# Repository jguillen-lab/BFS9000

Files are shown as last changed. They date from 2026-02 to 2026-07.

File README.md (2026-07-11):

# BFS9000 — Umbrella repository (hardware + firmware + software)

> 🇪🇸 **¿Prefieres leer esto en español?** → [README.es.md](README.es.md)

Main repository that groups several subprojects around the **BFS9000** keyboard (hardware) and its ecosystem of **QMK/Vial firmware** and **PC software** to control lighting over the network (Home Assistant via MQTT, with a local agent that talks to the keyboard over USB).

<p align="center">
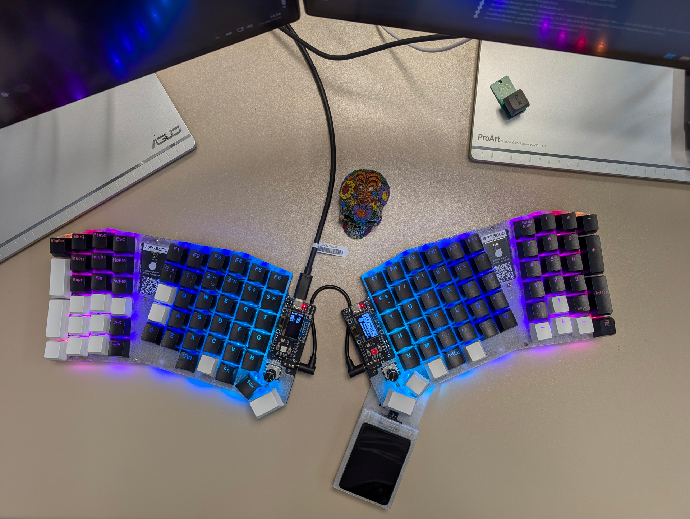
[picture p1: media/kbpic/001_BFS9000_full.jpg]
BFS9000 full keyboard
  
</p>

<p align="center">
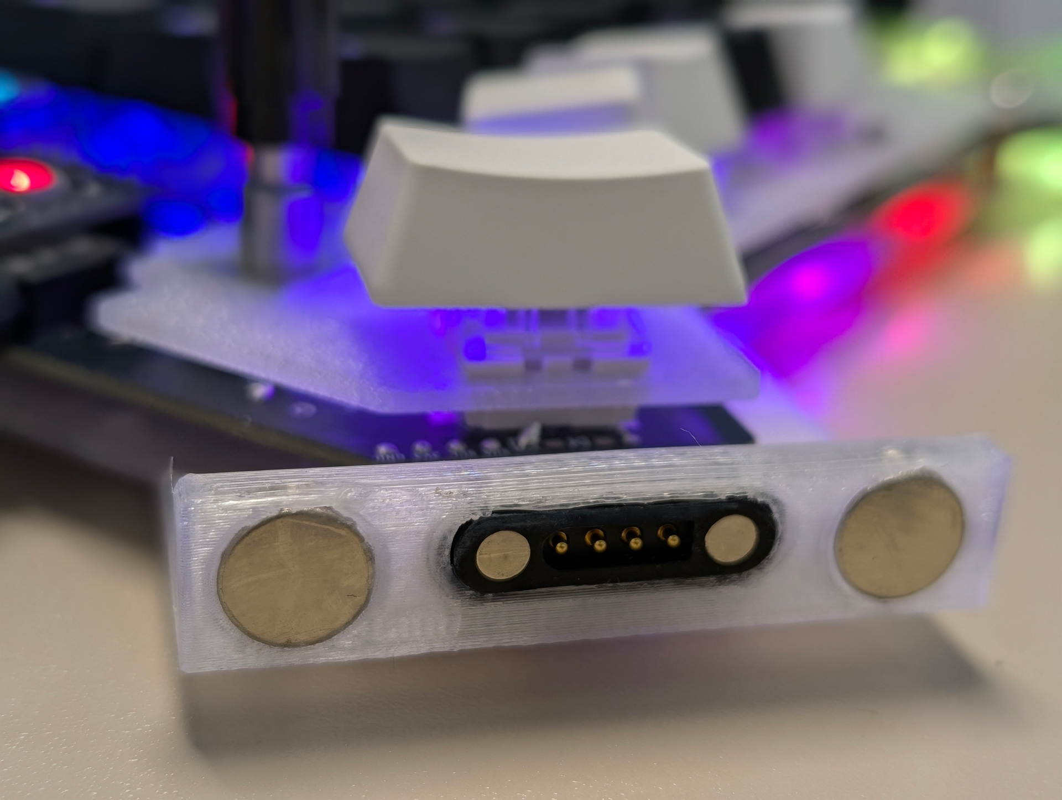
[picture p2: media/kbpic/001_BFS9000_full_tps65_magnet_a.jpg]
BFS9000 TPS65 magnet view A
  
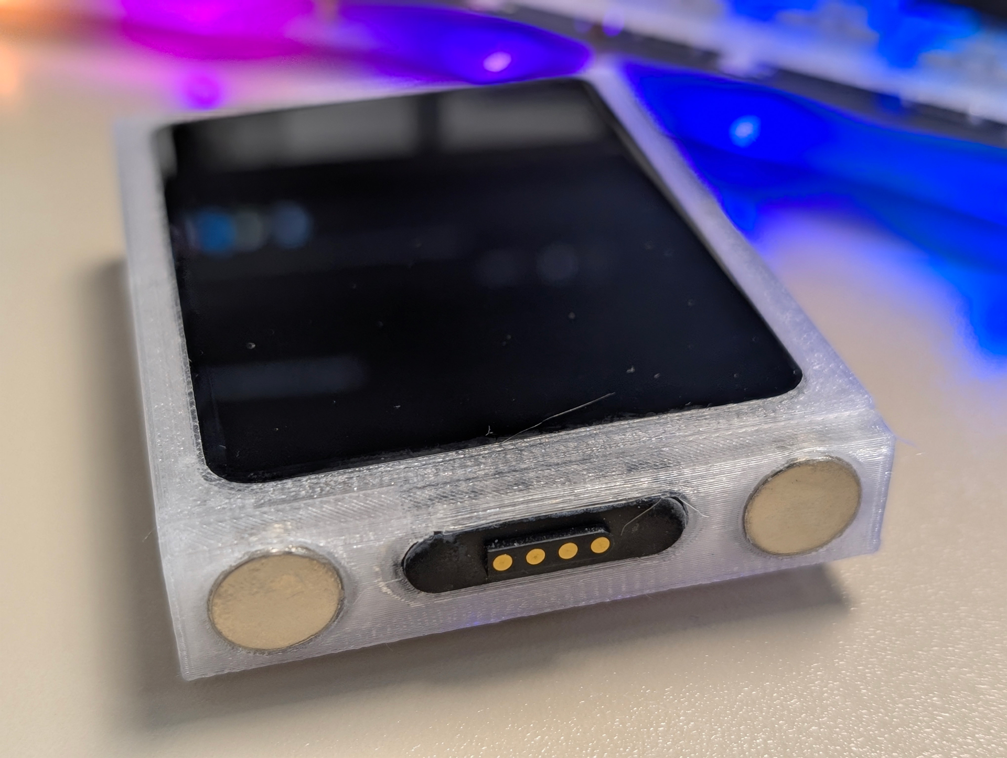
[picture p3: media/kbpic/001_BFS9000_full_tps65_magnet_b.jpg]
BFS9000 TPS65 magnet view B
  
</p>

## Repository structure

- [`hardware/`](./hardware/) — keyboard/PCB design (BFS9000) and related documentation.
- [`firmware/`](./firmware/) — firmware based on QMK/Vial, including configuration, keymaps, and related files.
- [`software/`](./software/) — PC agent/CLI for USB, MQTT, and Home Assistant integration.
- [`media/`](./media/) — general multimedia assets used throughout the project, such as images, videos, and other shared resources.
- [`hodgepodge/`](./hodgepodge/) — tests, experiments, and auxiliary material.
- [Wiki](https://github.com/jguillen-lab/BFS9000/wiki) — extended project documentation, guides, and additional reference material.

> Each folder should (or will eventually) have its own README with specific instructions.

## Community builds

Built your own BFS9000? Show it off here! Instructions and a ready-to-use template: [`media/kbpic/README.md`](media/kbpic/README.md). See the full gallery: [`media/GALLERY.md`](media/GALLERY.md).

<p align="center">
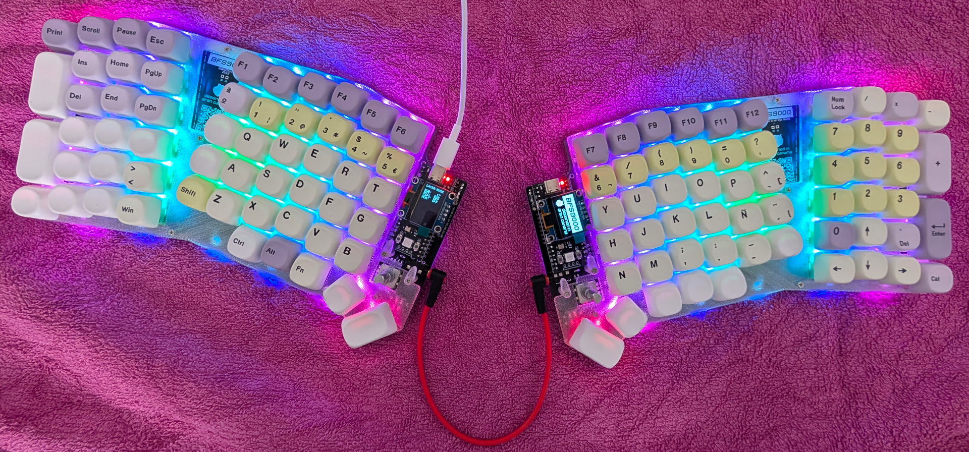
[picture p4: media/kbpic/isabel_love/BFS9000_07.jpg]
  
</p>

<p align="center"><i>Isabel Love — <a href="media/kbpic/isabel_love/README.md">more photos</a></i></p>

## Motivation

Standard keyboards never worked for me: I’d always end up placing them diagonally, and the classic staggered layout eventually took its toll (discomfort and some finger deformation). About ~10 years ago I got into the custom keyboard world and started looking for split, more ergonomic options: first I looked at commercial designs like the ErgoDox, then I tried the Corne, until I finally found the **[Sofle](https://github.com/josefadamcik/SofleKeyboard)**, originally designed and maintained by **Josef Adamčík**.

My first keyboard purchase was from **[Mechboards (UK)](https://mechboards.co.uk/)**. My first build attempt was a disaster, but in my case they were really helpful with support. (Note: their returns/warranty policy may differ today and, as they indicate, it usually doesn’t cover modified/soldered products; check it before buying.)
- Current policy (reference): https://mechboardsuk.reamaze.com/kb/shipping-and-returns/returns-policy

My second Sofle was a **Sofle RGB** from **[KeyHive](https://keyhive.xyz/shop/sofle)**. Within the Sofle ecosystem, the **Sofle RGB** variant (per-key RGB + underglow) is commonly attributed as a contribution by **Dane Evans** to the Sofle project.

Over time I’ve had other keyboards based on Sofle with small modifications and even had custom PCBs manufactured. The change was real: my fingers improved and my speed went up; in fact, when I go back to a staggered keyboard now I feel incredibly clumsy.

Even so, although I set up layers and learned to use them comfortably, I’m not the kind of person who “lives” in layers. After ~8 years using the Sofle I decided to try a **[BFO9000](https://docs.keeb.io/bfo-9000-build-guide)** (de **Keebio**) in its full configuration. Ergonomically I like it much less, but it solved my day-to-day better.

I thought that missing the Sofle would fade with time… but it didn’t. That’s why I’m in the process of creating a **BFS9000**, based on JellyTitan’s latest iteration called **[Sofle-Pico](https://github.com/JellyTitan/Sofle-Pico)**:

## Variants and combinations

One of the main goals of BFS9000 is flexibility.

The same PCB can be used to build multiple physical configurations, allowing different combinations of enclosures, plates and trackpad-related parts.

In total, the current design supports **16 different combinations** from the same PCB base.

<p align="center">
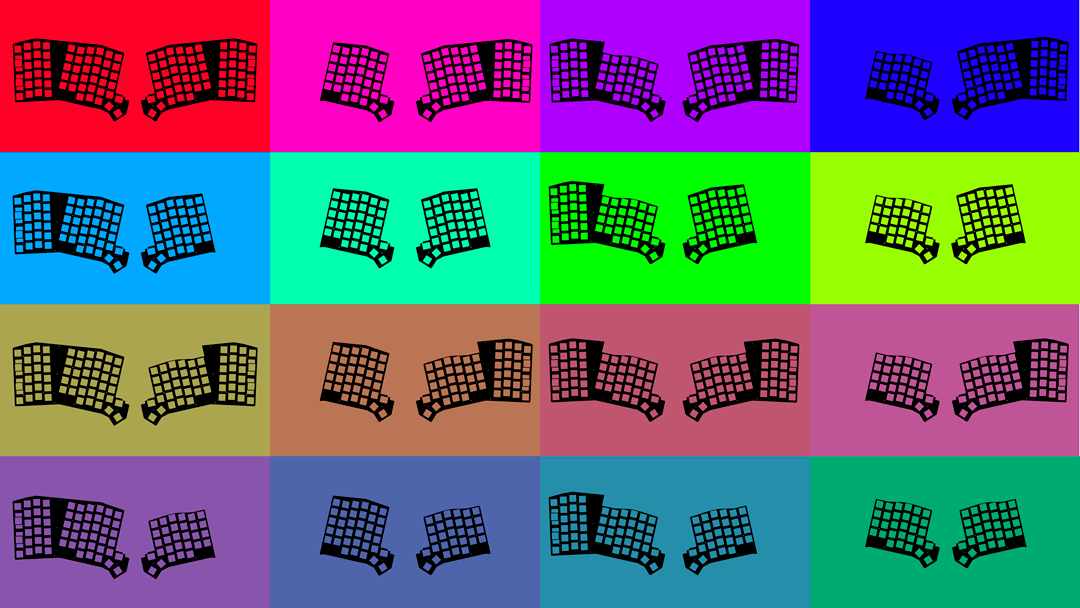
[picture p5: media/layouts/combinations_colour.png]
BFS9000 combinations overview
  
</p>

## Subprojects (quick links)

- BFS9000 hardware: [`hardware/`](./hardware/)
- Firmware (QMK/Vial): [`firmware/`](./firmware/)
- Software (PC agent / MQTT / HA): [`software/`](./software/)
- Auxiliary material: [`hodgepodge/`](./hodgepodge/)

## References

### Designs
- Sofle (Josef Adamčík): https://github.com/josefadamcik/SofleKeyboard
- Sofle-Pico (JellyTitan): https://github.com/JellyTitan/Sofle-Pico
- Sofle-Pico docs/site: https://www.soflepico.com/
- BFO-9000 (Keebio): https://docs.keeb.io/bfo-9000-build-guide

### Stores
- Mechboards: https://mechboards.co.uk/
- KeyHive (Sofle RGB): https://keyhive.xyz/shop/sofle

### Firmware / HA
- Vial (manual): https://get.vial.today/manual/
- Home Assistant MQTT: https://www.home-assistant.io/integrations/mqtt/
- Home Assistant MQTT Light: https://www.home-assistant.io/integrations/light.mqtt/

## License

**EN:** This repository uses **multiple licenses**. The applicable license(s) for each component are included in a `LICENSE` file within the **relevant directory**.

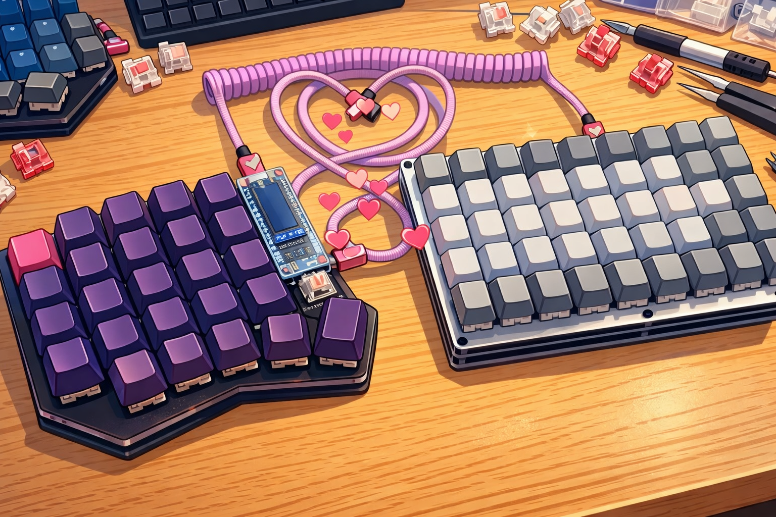
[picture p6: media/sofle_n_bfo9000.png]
Sofle y BFO9000


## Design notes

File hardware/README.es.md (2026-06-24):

# Hardware BFS9000

> 🇬🇧 **Prefer to read this in English?** → [README.md](README.md)

Esta carpeta contiene los ficheros de hardware de **BFS9000**, un teclado split diseñado por Jesús Guillén.

La revisión estable actual de hardware es la **0.4**.

---

## 1) Estructura de carpetas

```text
hardware/
├── BFS9000/              Ficheros fuente KiCad de la PCB principal
├── production/           Ficheros listos para fabricación
│   └── rev0.4/
│       ├── pcb/          Gerbers y taladros de la PCB principal
│       └── plates/       Ficheros de switch plate y bottom plate opcionales
└── enclosures/           Ficheros de carcasa y corte láser/CNC
    └── rev0.4/
```

La carpeta `BFS9000/` contiene el proyecto KiCad editable.

La carpeta `production/` contiene ficheros pensados para enviarse directamente a fabricar.

La carpeta `enclosures/` contiene ficheros opcionales de carcasa y ficheros para corte CNC/láser.

---

## 2) Revisiones de hardware

### Revisión 0.2

La revisión **0.2** usaba una **PCB de cuatro capas**.

Esta revisión tenía un fallo fatal de hardware causado por una huella incorrecta en los LEDs. Se conserva únicamente como referencia histórica y no debería usarse para fabricar nuevas placas.

### Revisión 0.3

La revisión **0.3** corrigió los fallos críticos encontrados en la revisión 0.2.

Además, cambió la PCB de **cuatro capas a dos capas**, simplificando el diseño y facilitando su fabricación.

### Revisión 0.4

La revisión **0.4** es la revisión estable actual de hardware.

Mantiene las correcciones de la revisión 0.3 y optimiza la PCB de forma general.

---

## 3) Ficheros de producción

Los ficheros listos para fabricar de la revisión 0.4 están en:

```text
hardware/production/rev0.4/
```

### PCB principal

```text
hardware/production/rev0.4/pcb/
└── BFS9000-rev0.4-pcb-gerbers-drill.zip
```

Este archivo contiene los Gerbers y taladros de la PCB principal de BFS9000.

También se incluyen estas imágenes de previsualización:

```text
BFS9000-rev0.4-gerber-preview.png
BFS9000-rev0.4-drill-preview.png
```

### Placas opcionales

```text
hardware/production/rev0.4/plates/
├── BFS9000-rev0.4-switch-plate.zip
└── BFS9000-rev0.4-bottom-plate.zip
```

La **BFS9000 switch plate** y la **BFS9000 bottom plate** son opcionales.

Normalmente se fabrican en **PMMA**.

---

## 4) Carcasas y ficheros CNC

Los ficheros de carcasa de la revisión 0.4 están en:

```text
hardware/enclosures/rev0.4/
```

### Serie A — carcasa seccionable

Los ficheros que empiezan por `A_` pertenecen a la versión de carcasa **seccionable**.

Se usa:

```text
A_BFS9000_sectionable_switch.3mf
```

Y después se elige solo una pieza inferior:

```text
A_BFS9000_sectionable_bottom.3mf
A_BFS9000_sectionable_bottom_tps65.3mf
```

Usa la versión `*_tps65` si el montaje del teclado incluye el **trackpad TPS65**.

### Serie B — carcasa completa

Los ficheros que empiezan por `B_` pertenecen a la versión de carcasa **completa**, no seccionable.

Esta versión solo sirve para la versión completa del teclado:

```text
B_BFS9000_full_switch.3mf
B_BFS9000_full_bottom.3mf
B_BFS9000_full_bottom_tps65.3mf
```

Usa la pieza inferior `*_tps65` si el montaje del teclado incluye el **trackpad TPS65**.

### Serie C — carcasa completa con ventana

Los ficheros que empiezan por `C_` pertenecen a la versión de carcasa **completa**, no seccionable, con ventana.

La ventana permite ver la zona decorativa de la PCB, como el logo, el QR, la dedicatoria u otros detalles:

```text
C_BFS9000_full_with_window_switch.3mf
C_BFS9000_full_with_window_bottom.3mf
C_BFS9000_full_bottom_with_window_tps65.3mf
```

Usa la pieza inferior `*_tps65` si el montaje del teclado incluye el **trackpad TPS65**.

### Serie X — piezas para TPS65

Los ficheros que empiezan por `X_` son específicos de la carcasa del **trackpad TPS65**:

```text
X_tps65_bottom.3mf
X_tps65_frame.3mf
X_tps65_main_bottom_addon.3mf
```

### Ficheros CNC / corte láser

Los ficheros que empiezan por `CNC_` están pensados para corte CNC o corte láser, por ejemplo en **PMMA**:

```text
CNC_bottom.dxf
CNC_switch.dxf
CNC_screen.dxf
```

---

## 5) Tag estable de hardware

La revisión estable 0.4 del hardware se marcará con este tag de Git:

```text
hardware/bfs9000-rev0.4
```

Los tags de Git siempre apuntan a un commit completo del repositorio, no a una carpeta individual.
Aun así, se puede restaurar solo la parte de hardware desde ese tag.

Para restaurar únicamente la carpeta de hardware a la revisión 0.4:

```bash
git restore --source hardware/bfs9000-rev0.4 -- hardware
```

Para comparar los ficheros actuales de hardware contra la revisión 0.4:

```bash
git diff hardware/bfs9000-rev0.4 -- hardware
```

---

## 6) Flujo recomendado

Con el repositorio limpio:

```bash
git status --short
```

Crear un tag anotado:

```bash
git tag -a hardware/bfs9000-rev0.4 -m "BFS9000 hardware revision 0.4 stable"
```

Subir el tag a GitHub:

```bash
git push origin hardware/bfs9000-rev0.4
```

---

## 7) Licencia

Salvo que se indique lo contrario, los ficheros de esta carpeta se distribuyen bajo la licencia del repositorio.

Consulta el fichero [LICENSE](../LICENSE) en la raíz del repositorio para más detalles.

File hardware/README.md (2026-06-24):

# BFS9000 Hardware

> 🇪🇸 **¿Prefieres leer esto en español?** → [README.es.md](README.es.md)

This directory contains the hardware files for **BFS9000**, a custom split keyboard designed by Jesús Guillén.

The current stable hardware revision is **0.4**.

---

## 1) Directory structure

```text
hardware/
├── BFS9000/              KiCad source files for the main PCB
├── production/           Manufacturing-ready files
│   └── rev0.4/
│       ├── pcb/          Main PCB Gerbers and drill files
│       └── plates/       Optional switch and bottom plate files
└── enclosures/           Case, enclosure and laser-cutting files
    └── rev0.4/
```

The `BFS9000/` directory contains the editable KiCad project files.

The `production/` directory contains files intended to be sent directly to a PCB manufacturer.

The `enclosures/` directory contains optional case/enclosure files and CNC/laser-cutting files.

---

## 2) Hardware revisions

### Revision 0.2

Revision **0.2** used a **four-layer PCB**.

This revision had a fatal hardware issue caused by an incorrect LED footprint. It is kept only as historical reference and should not be used for new boards.

### Revision 0.3

Revision **0.3** corrected the critical issues found in revision 0.2.

It also changed the PCB from **four layers to two layers**, making the design simpler and easier to manufacture.

### Revision 0.4

Revision **0.4** is the current stable hardware revision.

It keeps the fixes from revision 0.3 and generally optimises the PCB layout.

---

## 3) Production files

Manufacturing-ready files for revision 0.4 are stored in:

```text
hardware/production/rev0.4/
```

### Main PCB

```text
hardware/production/rev0.4/pcb/
└── BFS9000-rev0.4-pcb-gerbers-drill.zip
```

This archive contains the Gerber and drill files for the main BFS9000 PCB.

The following preview images are also included:

```text
BFS9000-rev0.4-gerber-preview.png
BFS9000-rev0.4-drill-preview.png
```

### Optional plates

```text
hardware/production/rev0.4/plates/
├── BFS9000-rev0.4-switch-plate.zip
└── BFS9000-rev0.4-bottom-plate.zip
```

The **BFS9000 switch plate** and **BFS9000 bottom plate** are optional.

They are normally manufactured from **PMMA**.

---

## 4) Enclosures and CNC files

Case and enclosure files for revision 0.4 are stored in:

```text
hardware/enclosures/rev0.4/
```

### A series — sectionable enclosure

Files starting with `A_` belong to the **sectionable** enclosure version.

Use:

```text
A_BFS9000_sectionable_switch.3mf
```

Then choose only one bottom part:

```text
A_BFS9000_sectionable_bottom.3mf
A_BFS9000_sectionable_bottom_tps65.3mf
```

Use the `*_tps65` version if the keyboard build includes the **TPS65 trackpad**.

### B series — full enclosure

Files starting with `B_` belong to the **full**, non-sectionable enclosure version.

This version is intended for the complete keyboard:

```text
B_BFS9000_full_switch.3mf
B_BFS9000_full_bottom.3mf
B_BFS9000_full_bottom_tps65.3mf
```

Use the `*_tps65` bottom if the keyboard build includes the **TPS65 trackpad**.

### C series — full enclosure with window

Files starting with `C_` belong to the **full**, non-sectionable enclosure version with a window.

The window is intended to expose the PCB decoration area, such as the logo, QR code, dedication or other artwork:

```text
C_BFS9000_full_with_window_switch.3mf
C_BFS9000_full_with_window_bottom.3mf
C_BFS9000_full_bottom_with_window_tps65.3mf
```

Use the `*_tps65` bottom if the keyboard build includes the **TPS65 trackpad**.

### X series — TPS65 enclosure parts

Files starting with `X_` are specific to the **TPS65 trackpad** enclosure:

```text
X_tps65_bottom.3mf
X_tps65_frame.3mf
X_tps65_main_bottom_addon.3mf
```

### CNC / laser-cutting files

Files starting with `CNC_` are intended for CNC or laser cutting, for example in **PMMA**:

```text
CNC_bottom.dxf
CNC_switch.dxf
CNC_screen.dxf
```

---

## 5) Stable hardware tag

The stable hardware revision 0.4 is intended to be marked with this Git tag:

```text
hardware/bfs9000-rev0.4
```

Git tags always point to a full repository commit, not to an individual folder.
However, the hardware folder can be restored independently from that tag.

To restore only the hardware directory to revision 0.4:

```bash
git restore --source hardware/bfs9000-rev0.4 -- hardware
```

To compare the current hardware files against revision 0.4:

```bash
git diff hardware/bfs9000-rev0.4 -- hardware
```

---

## 6) Recommended workflow

With a clean repository:

```bash
git status --short
```

Create an annotated tag:

```bash
git tag -a hardware/bfs9000-rev0.4 -m "BFS9000 hardware revision 0.4 stable"
```

Push the tag to GitHub:

```bash
git push origin hardware/bfs9000-rev0.4
```

---

## 7) Licence

Unless stated otherwise, the files in this directory are distributed under the repository licence.

See the root [LICENSE](../LICENSE) file for details.

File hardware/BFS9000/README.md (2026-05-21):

# BFS9000 — Hardware

> 🇪🇸 **¿Prefieres leer esto en español?** ? [README.es.md](README.es.md)

Hardware directory for the **BFS9000** keyboard.

> **Work in progress**
>
> This hardware is currently under active development and is **not functional yet**.
> Version `0.4` should be considered an early prototype intended only for validation and iteration.
>
> Do **not** treat the current design, PCB, schematics, footprints, BOM, or documentation as final or production-ready.
> Expect breaking changes, missing features, design errors, and incomplete documentation.

## Status

- Current version: `0.4`
- Development stage: prototype / WIP
- Functional status: **not working yet**

## Notes

This directory is intended to track the ongoing hardware development of the BFS9000.
At this stage, the project is still evolving and substantial changes are expected before it becomes usable.

## License and attribution

This hardware directory is licensed under the MIT License unless otherwise stated.

BFS9000 contains original work as well as files, ideas, references, or derived work from other open-source keyboard projects and component libraries.

See:

- [LICENSE](LICENSE)
- [NOTICE.md](NOTICE.md)

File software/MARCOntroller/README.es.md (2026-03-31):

# MARCOntroller — Guía de uso

> 🇬🇧 **Prefer to read this in English?** → [README.md](README.md)

Control de LEDs **Marquichuelo** (QMK + Vial/VialRGB) por **USB HID** usando **VialRGB**.

MARCOntroller incluye actualmente varias capas:

- **CLI** para pruebas y control directo por USB HID.
- **UI de escritorio** para control local, configuración y gestión del servicio.
- **Agente MQTT** para integración con **Home Assistant**.
- **Servicio del sistema** para ejecución persistente en segundo plano.

La comunicación con el teclado usa el **interfaz RAW HID de VIA/Vial** (usagePage `0xFF60`, usage `0x0061`) y los comandos **VialRGB** ya presentes en el firmware, sin necesidad de añadir un `raw_hid_receive()` propio.

---

## 1) Requisitos

### Firmware

- Teclado con **Vial** y **VialRGB** habilitados (`VIALRGB_ENABLE = yes` + `RGB_MATRIX_ENABLE = yes`).
- Para control **LED a LED**: debe estar compilado el modo **VIALRGB_DIRECT** (si `get-led-count` funciona, lo tienes).

### PC

- Rust toolchain instalado (`rustc`, `cargo`).
- Drivers USB HID estándar.
- En **Windows**, si compilas con MSVC: Build Tools (C++ toolset + Windows SDK).
- En **Linux**, `hidapi` puede requerir dependencias del sistema como `libudev-dev` y `libhidapi-dev`.
- En **macOS**, el acceso HID usa las APIs del sistema.

---

## 2) Estructura del proyecto

~~~text
MARCOntroller/
├── Cargo.toml
├── rustfmt.toml
├── README.md
├── README.es.md
├── locales/
│   ├── en.yml
│   └── es.yml
└── src/
    ├── main.rs         ← entrada, logging, idioma y dispatch
    ├── cli.rs          ← comandos clap + salida localizada
    ├── config.rs       ← carga/guardado de config TOML
    ├── logging.rs      ← inicialización de logging
    ├── ui.rs           ← interfaz de escritorio (egui/eframe)
    ├── agent/
    │   ├── mod.rs
    │   ├── runtime.rs  ← entrada compartida del agente
    │   └── mqtt.rs     ← MQTT + Home Assistant Discovery
    ├── keyboard/
    │   ├── mod.rs
    │   ├── hid.rs      ← transporte USB HID
    │   └── vialrgb.rs  ← protocolo VialRGB
    └── service/
        ├── mod.rs
        ├── control.rs  ← gestión del servicio del sistema
        └── windows.rs  ← entrada del Windows Service
~~~

Separación por capas:

- `keyboard/` agrupa el acceso al teclado y el protocolo VialRGB.
- `agent/` agrupa el runtime del agente MQTT y la integración con Home Assistant.
- `service/` agrupa la gestión del servicio del sistema por plataforma.
- `ui.rs` contiene la aplicación de escritorio.
- `cli.rs` mantiene la interfaz de línea de comandos.

Los módulos de `keyboard/` no muestran salida al usuario: devuelven `Result<T>` y se reutilizan desde la CLI, la UI y el agente.

---

## 3) Modos de uso

### CLI

Útil para pruebas rápidas, depuración USB HID y automatizaciones locales simples.

```bat
cargo run -- <comando> [args...]
```

### UI de escritorio

Abre la aplicación local:

```bat
cargo run -- ui
```

La UI permite:

- controlar color, brillo, efecto y velocidad;
- controlar LEDs individuales en modo DIRECT;
- editar y guardar la configuración;
- gestionar el servicio del sistema;
- ver el estado del teclado, el estado del servicio y la comparación entre ejecutable actual y ejecutable registrado en el servicio.

### Agente MQTT

Arranca el agente usando la configuración persistente:

```bat
cargo run -- agent
```

### Servicio del sistema

Subcomandos disponibles:

```bat
cargo run -- service-install
cargo run -- service-start
cargo run -- service-stop
cargo run -- service-uninstall
```

El subcomando `service` existe como entrada de ejecución persistente del servicio y normalmente lo usa el propio gestor de servicios, no el usuario final.

---

## 4) Compilar y ejecutar

Desde la carpeta del proyecto:

```bat
cargo build
cargo run -- <comando> [args...]
```

Binario release:

```bat
cargo build --release
.\target\release\MARCOntroller.exe --help
```

Formateo y comprobación básica:

```bat
cargo fmt
cargo clippy
cargo build
```

---

## 5) Idioma de la interfaz

Los mensajes del programa están disponibles en **inglés** (`en`) y **español** (`es`).

El idioma se selecciona por orden de prioridad:

| Prioridad | Mecanismo | Ejemplo |
|---|---|---|
| 1ª | Flag `--lang` | `cargo run -- --lang es off` |
| 2ª | Variable `MARCOCONTROLLER_LANG` | `set MARCOCONTROLLER_LANG=es` |
| 3ª | `LC_ALL` / `LC_MESSAGES` / `LANG` / `LANGUAGE` | `set LANG=es_ES.UTF-8` |
| 4ª | Idioma del sistema | detectado automáticamente |
| 5ª | Por defecto | inglés |

```bat
cargo run -- --lang es get-info
$env:MARCOCONTROLLER_LANG = "es"
cargo run -- get-info
cargo run -- --lang en get-info
```

Para añadir un idioma nuevo: crear `locales/<código>.yml` con las mismas claves que `en.yml`.

---

## 6) Configuración persistente

MARCOntroller usa un `config.toml` persistente para la UI, el agente MQTT y el servicio del sistema.

Comandos disponibles:

```bat
cargo run -- config path
cargo run -- config init
cargo run -- config show
```

- `config path` imprime la ruta resuelta.
- `config init` crea un `config.toml` por defecto.
- `config show` muestra el contenido actual.

`config init` toma los valores HID de los flags actuales (`--vid`, `--pid`, `--serial`) para sembrar el fichero inicial.

### Campos principales

#### HID

- `vid`
- `pid`
- `serial` opcional

#### MQTT

- `host`
- `port`
- `username`
- `password`
- `client_id`
- `keep_alive_secs`
- `retain_discovery`
- `retain_state`

#### Home Assistant

- `discovery_prefix`
- `object_id`
- `name`
- `unique_id`
- `base_topic`
- `publish_discovery_on_start`
- `republish_on_ha_birth`

---

## 7) Selección de dispositivo

Por defecto usa:

- VID: `FEED`
- PID: `0000`
- Interfaz RAW HID preferida: usagePage `FF60`, usage `0061`
- Fallback: `interface_number == 1` o `MI_01` en la ruta

Todos los comandos aceptan opcionalmente:

```bat
--vid FEED --pid 0000 --serial "vial:f64c2b3c" --lang es
```

Si tienes varios teclados iguales, filtra por serial:

```bat
cargo run -- --serial "vial:f64c2b3c" get-info
```

> El serial lo puedes ver con `cargo run -- list`.

---

## 8) MQTT + Home Assistant

El agente publica **MQTT Discovery** para una entidad `light` y también una entidad `number` separada para la **velocidad del efecto**.

### Topics derivados de la configuración

Con los valores por defecto:

- Discovery light: `homeassistant/light/marcontroller_keyboard/config`
- Topic de control: `kb/pc01/light/set`
- Topic de estado: `kb/pc01/light/state`
- Topic de disponibilidad: `kb/pc01/availability`
- Discovery de velocidad: `homeassistant/number/marcontroller_keyboard_effect_speed/config`
- Topic de velocidad: `kb/pc01/light/effect_speed/set`
- Topic de estado de velocidad: `kb/pc01/light/effect_speed/state`

### Payloads de ejemplo

Encender con color:

```json
{"state":"ON","color":{"r":255,"g":80,"b":20},"brightness":128}
```

Apagar:

```json
{"state":"OFF"}
```

Cambiar efecto:

```json
{"effect":"Breathing"}
```

Cambiar velocidad del efecto:

```text
120
```

### Comportamiento relevante

- El agente publica `availability` como `online` / `offline`.
- Si el teclado desaparece, el agente lo trata como condición normal de “offline”.
- Al arrancar Home Assistant de nuevo, el agente puede republicar discovery y volver a sincronizar el estado si `republish_on_ha_birth = true`.
- El agente relee periódicamente el estado real del teclado para reflejar cambios hechos desde la UI, Vial u otras herramientas HID.

---

## 9) Servicio del sistema

La UI y la CLI exponen instalación, arranque, parada y desinstalación del servicio.

### Lo que ya hace el proyecto

- Gestiona instalación, arranque, parada y desinstalación.
- Fuera de Windows, el modo `service` admite parada limpia por señal.
- La UI muestra:
  - estado del servicio;
  - backend detectado;
  - mecanismo de elevación disponible;
  - ruta del ejecutable actual;
  - ruta registrada en el servicio;
  - comparación entre ambas rutas.

### Logging en modo servicio

En modo `service`, el logging se redirige a fichero.

Ruta preferida:

- carpeta `logs/` junto al `config.toml` usado por el servicio;

fichero:

- `service.log`

Si no hay `--config` explícito, se intenta resolver el directorio de logs a partir de la ruta de config por defecto.

### Nota importante

Instala el servicio solo cuando el ejecutable ya esté en su ubicación definitiva. La UI compara esa ruta con la ruta registrada del servicio precisamente para ayudar a detectar desajustes.

---

## 10) Comandos CLI disponibles

### `list`

Lista lo que **HIDAPI** ve para el VID/PID.

```bat
cargo run -- list
```

### `get-info`

Lee versión de protocolo VialRGB y brillo máximo.

```bat
cargo run -- get-info
```

### `get-mode`

Lee modo, velocidad y HSV actuales.

```bat
cargo run -- get-mode
```

### `supported`

Lista IDs de efectos soportados.

```bat
cargo run -- supported
```

### `off`

Apaga los LEDs.

```bat
cargo run -- off
```

### `set-effect`

Establece un efecto por ID VialRGB.

```bat
cargo run -- set-effect --id 6 --speed 100 --h 30 --s 255 --v 80
```

### `solid-hsv`

Atajo para `SOLID_COLOR` (ID 2) usando HSV.

```bat
cargo run -- solid-hsv --h 0 --s 255 --v 128
```

### `solid-rgb`

Atajo para `SOLID_COLOR` desde RGB.

```bat
cargo run -- solid-rgb --r 255 --g 0 --b 255
```

### `set-brightness`

Cambia solo el brillo `V`, preservando modo, velocidad, `H` y `S`.

```bat
cargo run -- set-brightness --v 20
```

### `get-led-count`

Devuelve `RGB_MATRIX_LED_COUNT`.

```bat
cargo run -- get-led-count
```

### `get-led-info`

Devuelve metadatos de un LED.

```bat
cargo run -- get-led-info --index 0
```

### `direct-all-hsv`

Activa DIRECT y pinta todos los LEDs.

```bat
cargo run -- direct-all-hsv --h 170 --s 255 --v 64
```

### `direct-led-hsv`

Setea un LED concreto.

```bat
cargo run -- direct-led-hsv --index 2 --h 170 --s 255 --v 64
```

### `config`

Gestiona la configuración persistente.

```bat
cargo run -- config path
cargo run -- config init
cargo run -- config show
```

### `agent`

Arranca el agente MQTT.

```bat
cargo run -- agent
```

### `ui`

Abre la interfaz de escritorio.

```bat
cargo run -- ui
```

### `service-install`, `service-start`, `service-stop`, `service-uninstall`

Gestionan el servicio del sistema.

```bat
cargo run -- service-install
cargo run -- service-start
cargo run -- service-stop
cargo run -- service-uninstall
```

---

## 11) Control LED a LED (modo DIRECT)

> Requisito: que el firmware tenga `VIALRGB_DIRECT` compilado.

### `get-led-count`

```bat
cargo run -- get-led-count
```

### `get-led-info`

Devuelve:

- `x`, `y`
- `flags`
- `matrix_row`, `matrix_col`

### `direct-all-hsv`

1. Pone el modo `DIRECT` (ID 1)
2. Setea todos los LEDs al mismo HSV

### `direct-led-hsv`

Setea un LED concreto.

> Recomendación: activa primero DIRECT con `direct-all-hsv` o `set-effect --id 1`.

---

## 12) UI de escritorio

La UI actual tiene tres pestañas principales:

- **Control**
- **LED a LED (DIRECT)**
- **Configuración**

### Pestaña Control

- selector de efecto
- velocidad
- color
- brillo
- auto-aplicación con debounce
- gestión del servicio del sistema

### Pestaña DIRECT

- lectura del número de LEDs
- selección de índice
- color y brillo
- aplicar a LED seleccionado
- aplicar a todos los LEDs

### Pestaña Configuración

- edición de HID
- edición de MQTT
- edición de Home Assistant
- recarga y guardado
- reinicio del agente MQTT tras guardar

---

## 13) Tests y comprobaciones

Sin necesidad de teclado conectado:

```bat
cargo build
cargo clippy
cargo run -- --lang es get-info
cargo run -- --lang en get-info
```

Con teclado conectado, orden recomendado:

```bat
cargo run -- list
cargo run -- get-info
cargo run -- get-mode
cargo run -- supported
cargo run -- off
cargo run -- solid-rgb --r 255 --g 0 --b 0
cargo run -- set-brightness --v 128
cargo run -- get-led-count
cargo run -- ui
```

---

## 14) Notas y limitaciones

- **No hay lectura del color por LED** con VialRGB; el modo DIRECT permite escritura por `fastset`, no lectura del color individual.
- En Windows, el report HID incluye un **ReportID=0** adicional; por eso se escriben 33 bytes y se leen 32.
- Si compilas con `x86_64-pc-windows-msvc` y falla el enlace con `msvcrt.lib`:
  - usa **Developer PowerShell**, o
  - carga `VsDevCmd.bat` antes de `cargo build`.
- El soporte de servicio y la detección mostrada en la UI son multiplataforma, pero conviene validar el flujo completo en cada sistema antes de distribuir binarios.

---

## 15) Ejemplos rápidos

```bat
cargo run -- config init
cargo run -- config path
cargo run -- ui
cargo run -- agent
cargo run -- solid-hsv --h 0 --s 255 --v 64
cargo run -- solid-rgb --r 255 --g 0 --b 255
cargo run -- set-brightness --v 20
cargo run -- off
cargo run -- direct-all-hsv --h 0 --s 0 --v 0
cargo run -- direct-led-hsv --index 0 --h 0   --s 255 --v 64
cargo run -- direct-led-hsv --index 1 --h 85  --s 255 --v 64
cargo run -- direct-led-hsv --index 2 --h 170 --s 255 --v 64
cargo run -- service-install
cargo run -- service-start
```

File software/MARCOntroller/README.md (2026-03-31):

# MARCOntroller — User Guide

> 🇪🇸 **¿Prefieres leer esto en español?** → [README.es.md](README.es.md)

Control **Marquichuelo** LEDs (QMK + Vial/VialRGB) over **USB HID** using **VialRGB**.

MARCOntroller currently includes several layers:

- a **CLI** for direct USB HID testing and control;
- a **desktop UI** for local control, configuration and service management;
- an **MQTT agent** for **Home Assistant** integration;
- a **system service** mode for persistent background execution.

The tool communicates with the keyboard through the **VIA/Vial RAW HID interface** (usagePage `0xFF60`, usage `0x0061`) and uses the **VialRGB** commands already present in the firmware, without requiring a custom `raw_hid_receive()` implementation.

---

## 1) Requirements

### Firmware

- Keyboard with **Vial** and **VialRGB** enabled (`VIALRGB_ENABLE = yes` + `RGB_MATRIX_ENABLE = yes`).
- For **per-LED control**: `VIALRGB_DIRECT` must be compiled in (if `get-led-count` works, you have it).

### PC

- Rust toolchain installed (`rustc`, `cargo`).
- Standard USB HID drivers.
- On **Windows**, if you build with MSVC: Build Tools (C++ toolset + Windows SDK).
- On **Linux**, `hidapi` may require system packages such as `libudev-dev` and `libhidapi-dev`.
- On **macOS**, HID access uses the native system APIs.

---

## 2) Project structure

~~~text
MARCOntroller/
├── Cargo.toml
├── rustfmt.toml
├── README.md
├── README.es.md
├── locales/
│   ├── en.yml
│   └── es.yml
└── src/
    ├── main.rs         ← entry point, logging, locale and dispatch
    ├── cli.rs          ← clap commands + localised output
    ├── config.rs       ← TOML config load/save
    ├── logging.rs      ← logging initialisation
    ├── ui.rs           ← desktop UI (egui/eframe)
    ├── agent/
    │   ├── mod.rs
    │   ├── runtime.rs  ← shared agent entry point
    │   └── mqtt.rs     ← MQTT + Home Assistant Discovery
    ├── keyboard/
    │   ├── mod.rs
    │   ├── hid.rs      ← USB HID transport
    │   └── vialrgb.rs  ← VialRGB protocol
    └── service/
        ├── mod.rs
        ├── control.rs  ← system service management
        └── windows.rs  ← Windows Service entry point
~~~

Layer split:

- `keyboard/` groups keyboard access and the VialRGB protocol.
- `agent/` groups the MQTT runtime and Home Assistant integration.
- `service/` groups system-service management by platform.
- `ui.rs` contains the desktop application.
- `cli.rs` keeps the command-line interface.

The modules inside `keyboard/` do not print user-facing output: they return `Result<T>` and are reused by the CLI, the UI and the agent.

---

## 3) Usage modes

### CLI

Useful for quick tests, USB HID debugging and simple local automation.

```bat
cargo run -- <command> [args...]
```

### Desktop UI

Open the local application:

```bat
cargo run -- ui
```

The UI lets you:

- control colour, brightness, effect and speed;
- control individual LEDs in DIRECT mode;
- edit and save configuration;
- manage the system service;
- inspect keyboard status, service status and the comparison between the current executable and the executable registered in the service.

### MQTT agent

Start the agent using the persistent configuration:

```bat
cargo run -- agent
```

### System service

Available subcommands:

```bat
cargo run -- service-install
cargo run -- service-start
cargo run -- service-stop
cargo run -- service-uninstall
```

The `service` subcommand exists as the long-lived service entry point and is normally started by the service manager rather than manually.

---

## 4) Build and run

From the project folder:

```bat
cargo build
cargo run -- <command> [args...]
```

Release binary:

```bat
cargo build --release
.\target\release\MARCOntroller.exe --help
```

Formatting and basic checks:

```bat
cargo fmt
cargo clippy
cargo build
```

---

## 5) UI language

Messages are available in **English** (`en`) and **Spanish** (`es`).

Language is selected in priority order:

| Priority | Mechanism | Example |
|---|---|---|
| 1st | `--lang` flag | `cargo run -- --lang es off` |
| 2nd | `MARCOCONTROLLER_LANG` env var | `set MARCOCONTROLLER_LANG=es` |
| 3rd | `LC_ALL` / `LC_MESSAGES` / `LANG` / `LANGUAGE` | `set LANG=es_ES.UTF-8` |
| 4th | System locale | auto-detected |
| 5th | Built-in default | English |

```bat
cargo run -- --lang es get-info
$env:MARCOCONTROLLER_LANG = "es"
cargo run -- get-info
cargo run -- --lang en get-info
```

To add a new language: create `locales/<code>.yml` with the same keys as `en.yml`.

---

## 6) Persistent configuration

MARCOntroller uses a persistent `config.toml` for the UI, the MQTT agent and the system service.

Available commands:

```bat
cargo run -- config path
cargo run -- config init
cargo run -- config show
```

- `config path` prints the resolved config path.
- `config init` creates a default `config.toml`.
- `config show` prints the current contents.

`config init` seeds the HID fields from the current `--vid`, `--pid` and `--serial` flags.

### Main fields

#### HID

- `vid`
- `pid`
- optional `serial`

#### MQTT

- `host`
- `port`
- `username`
- `password`
- `client_id`
- `keep_alive_secs`
- `retain_discovery`
- `retain_state`

#### Home Assistant

- `discovery_prefix`
- `object_id`
- `name`
- `unique_id`
- `base_topic`
- `publish_discovery_on_start`
- `republish_on_ha_birth`

---

## 7) Device selection

Defaults:

- VID: `FEED`
- PID: `0000`
- Preferred RAW HID interface: usagePage `FF60`, usage `0061`
- Fallback: `interface_number == 1` or `MI_01` in the path

All commands optionally accept:

```bat
--vid FEED --pid 0000 --serial "vial:f64c2b3c" --lang es
```

If you have multiple identical keyboards, filter by serial:

```bat
cargo run -- --serial "vial:f64c2b3c" get-info
```

> Check the serial with `cargo run -- list`.

---

## 8) MQTT + Home Assistant

The agent publishes **MQTT Discovery** for a `light` entity and also a separate `number` entity for **effect speed**.

### Topics derived from the configuration

With default values:

- Light discovery: `homeassistant/light/marcontroller_keyboard/config`
- Command topic: `kb/pc01/light/set`
- State topic: `kb/pc01/light/state`
- Availability topic: `kb/pc01/availability`
- Speed discovery: `homeassistant/number/marcontroller_keyboard_effect_speed/config`
- Speed command topic: `kb/pc01/light/effect_speed/set`
- Speed state topic: `kb/pc01/light/effect_speed/state`

### Example payloads

Turn on with colour:

```json
{"state":"ON","color":{"r":255,"g":80,"b":20},"brightness":128}
```

Turn off:

```json
{"state":"OFF"}
```

Change effect:

```json
{"effect":"Breathing"}
```

Change effect speed:

```text
120
```

### Relevant behaviour

- The agent publishes `availability` as `online` / `offline`.
- If the keyboard disappears, the agent treats it as a normal offline condition.
- After a Home Assistant restart, the agent can republish discovery and resync the current state if `republish_on_ha_birth = true`.
- The agent periodically re-reads the real keyboard state so Home Assistant reflects changes made from the UI, Vial or other HID tools.

---

## 9) System service

The UI and the CLI expose install, start, stop and uninstall actions for the system service.

### What the project already does

- Manages install, start, stop and uninstall.
- Outside Windows, `service` mode supports clean shutdown by signal.
- The UI shows:
  - service status;
  - detected backend;
  - available elevation mechanism;
  - current executable path;
  - path registered in the service;
  - comparison between both paths.

### Logging in service mode

In `service` mode, logging is redirected to a file.

Preferred location:

- a `logs/` directory next to the `config.toml` used by the service;

file:

- `service.log`

If there is no explicit `--config`, the code falls back to the default config directory to resolve the log directory.

### Important note

Install the service only once the executable is already in its final location. The UI compares that path against the path currently registered in the service to help detect mismatches.

---

## 10) Available CLI commands

### `list`

List what **HIDAPI** sees for the configured VID/PID.

```bat
cargo run -- list
```

### `get-info`

Read VialRGB protocol version and maximum brightness.

```bat
cargo run -- get-info
```

### `get-mode`

Read current mode, speed and HSV values.

```bat
cargo run -- get-mode
```

### `supported`

List supported effect IDs.

```bat
cargo run -- supported
```

### `off`

Turn all lighting off.

```bat
cargo run -- off
```

### `set-effect`

Set an effect by its VialRGB ID.

```bat
cargo run -- set-effect --id 6 --speed 100 --h 30 --s 255 --v 80
```

### `solid-hsv`

Shortcut for `SOLID_COLOR` (ID 2) using HSV.

```bat
cargo run -- solid-hsv --h 0 --s 255 --v 128
```

### `solid-rgb`

Shortcut for `SOLID_COLOR` from RGB.

```bat
cargo run -- solid-rgb --r 255 --g 0 --b 255
```

### `set-brightness`

Change only brightness `V`, preserving mode, speed, `H` and `S`.

```bat
cargo run -- set-brightness --v 20
```

### `get-led-count`

Return `RGB_MATRIX_LED_COUNT`.

```bat
cargo run -- get-led-count
```

### `get-led-info`

Return metadata for one LED.

```bat
cargo run -- get-led-info --index 0
```

### `direct-all-hsv`

Enable DIRECT and paint all LEDs.

```bat
cargo run -- direct-all-hsv --h 170 --s 255 --v 64
```

### `direct-led-hsv`

Set one LED.

```bat
cargo run -- direct-led-hsv --index 2 --h 170 --s 255 --v 64
```

### `config`

Manage persistent configuration.

```bat
cargo run -- config path
cargo run -- config init
cargo run -- config show
```

### `agent`

Start the MQTT agent.

```bat
cargo run -- agent
```

### `ui`

Open the desktop UI.

```bat
cargo run -- ui
```

### `service-install`, `service-start`, `service-stop`, `service-uninstall`

Manage the system service.

```bat
cargo run -- service-install
cargo run -- service-start
cargo run -- service-stop
cargo run -- service-uninstall
```

---

## 11) Per-LED control (DIRECT mode)

> Requirement: the firmware must include `VIALRGB_DIRECT`.

### `get-led-count`

```bat
cargo run -- get-led-count
```

### `get-led-info`

Returns:

- `x`, `y`
- `flags`
- `matrix_row`, `matrix_col`

### `direct-all-hsv`

1. Switches to `DIRECT` mode (ID 1)
2. Sets all LEDs to the same HSV colour

### `direct-led-hsv`

Sets one LED.

> Recommendation: enable DIRECT first with `direct-all-hsv` or `set-effect --id 1`.

---

## 12) Desktop UI

The current UI has three main tabs:

- **Control**
- **Per-LED (DIRECT)**
- **Config**

### Control tab

- effect selector
- speed
- colour
- brightness
- auto-apply with debounce
- system service management

### DIRECT tab

- read LED count
- select LED index
- colour and brightness
- apply to selected LED
- apply to all LEDs

### Config tab

- edit HID fields
- edit MQTT fields
- edit Home Assistant fields
- reload and save configuration
- restart the MQTT agent after saving

---

## 13) Tests and checks

Without the keyboard connected:

```bat
cargo build
cargo clippy
cargo run -- --lang es get-info
cargo run -- --lang en get-info
```

With the keyboard connected, recommended order:

```bat
cargo run -- list
cargo run -- get-info
cargo run -- get-mode
cargo run -- supported
cargo run -- off
cargo run -- solid-rgb --r 255 --g 0 --b 0
cargo run -- set-brightness --v 128
cargo run -- get-led-count
cargo run -- ui
```

---

## 14) Notes and limitations

- **There is no per-LED colour read-back** in VialRGB; DIRECT allows `fastset` writes, not per-LED readback.
- On Windows, the HID report includes an extra **ReportID=0** byte; that is why 33 bytes are written and 32 are read.
- If linking fails with `msvcrt.lib` when targeting `x86_64-pc-windows-msvc`:
  - use **Developer PowerShell**, or
  - load `VsDevCmd.bat` before `cargo build`.
- Service support and the detection shown in the UI are now multi-platform, but the full flow should still be validated on each target OS before distributing binaries.

---

## 15) Quick examples

```bat
cargo run -- config init
cargo run -- config path
cargo run -- ui
cargo run -- agent
cargo run -- solid-hsv --h 0 --s 255 --v 64
cargo run -- solid-rgb --r 255 --g 0 --b 255
cargo run -- set-brightness --v 20
cargo run -- off
cargo run -- direct-all-hsv --h 0 --s 0 --v 0
cargo run -- direct-led-hsv --index 0 --h 0   --s 255 --v 64
cargo run -- direct-led-hsv --index 1 --h 85  --s 255 --v 64
cargo run -- direct-led-hsv --index 2 --h 170 --s 255 --v 64
cargo run -- service-install
cargo run -- service-start
```

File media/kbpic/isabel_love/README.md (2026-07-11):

# Isabel Love's BFS9000
## Español

Estoy utilizando la configuración completa del teclado en ambas mitades. Para los sockets hot-swap he montado **Durock**, junto con interruptores **Outemu Silent Peach V3** y keycaps **PBT Taro** con perfil **MOA**. También he instalado separadores de **7 mm**, que encajan y funcionan sin ningún problema.

---

## English

I'm using the full keyboard configuration on both halves. For the hot-swap sockets, I'm using **Durock** sockets, along with **Outemu Silent Peach V3** switches and **PBT Taro** keycaps with the **MOA** profile. I also installed **7 mm** standoffs, which fit and work perfectly without any issues.

## Photos

<p align="center">
  
</p>

<p align="center">
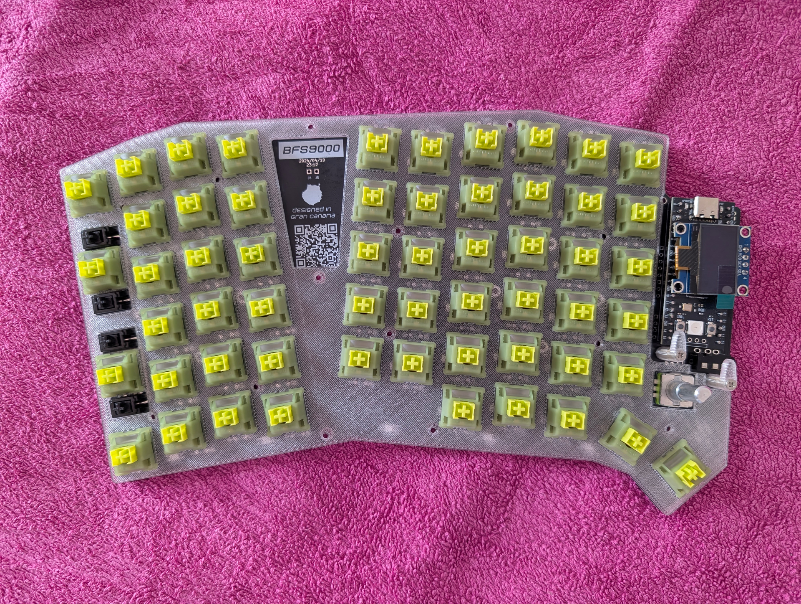
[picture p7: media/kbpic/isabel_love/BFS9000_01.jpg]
  
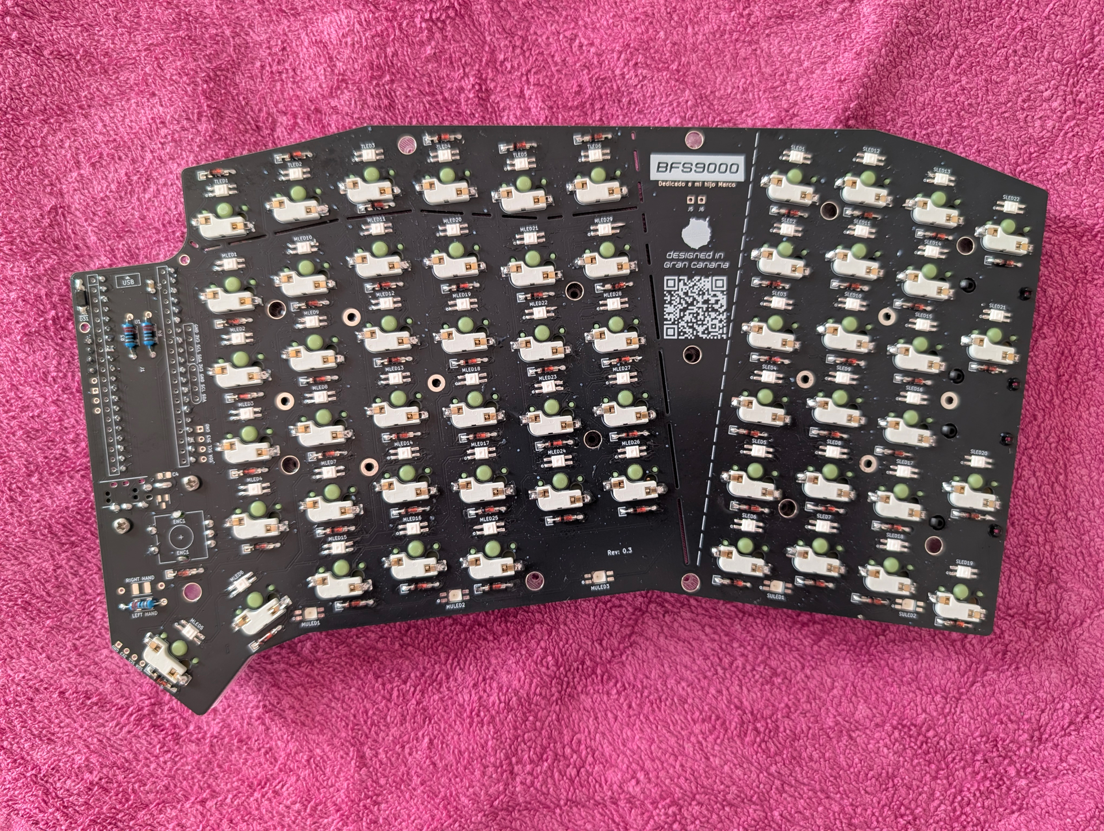
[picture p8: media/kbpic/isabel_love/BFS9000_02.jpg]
  
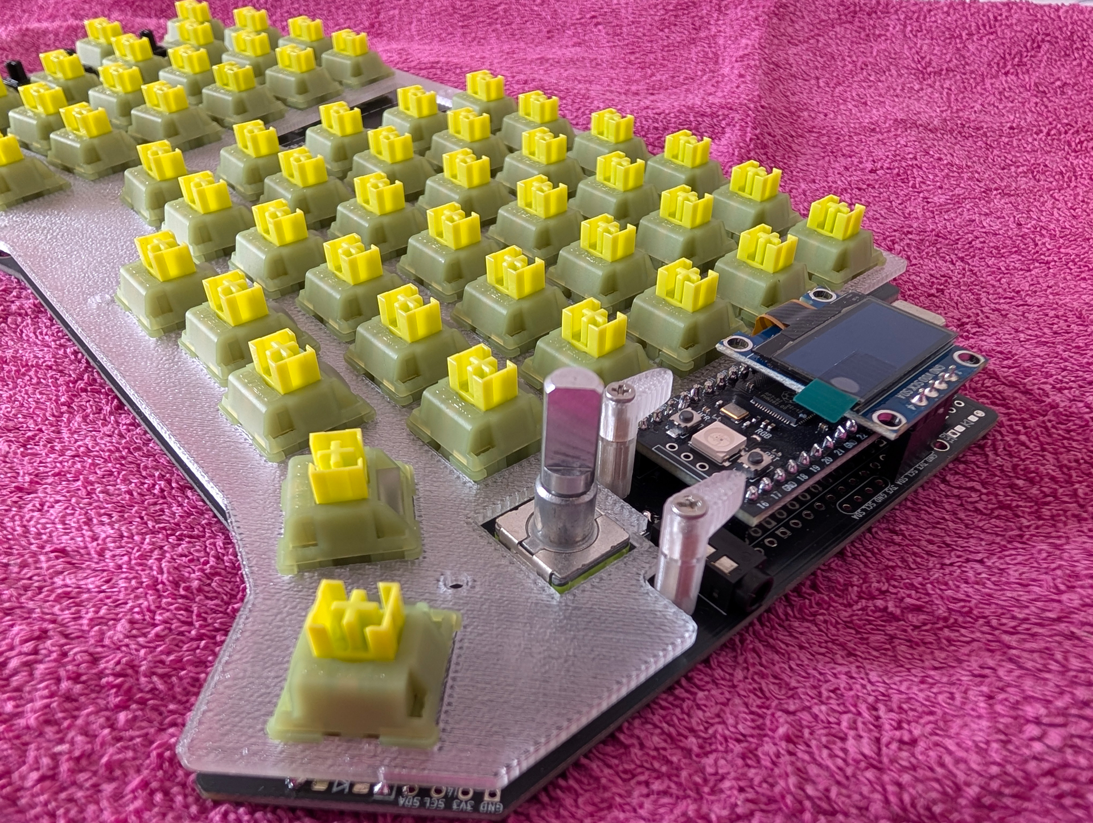
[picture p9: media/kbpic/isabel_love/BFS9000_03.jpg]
  
</p>

<p align="center">
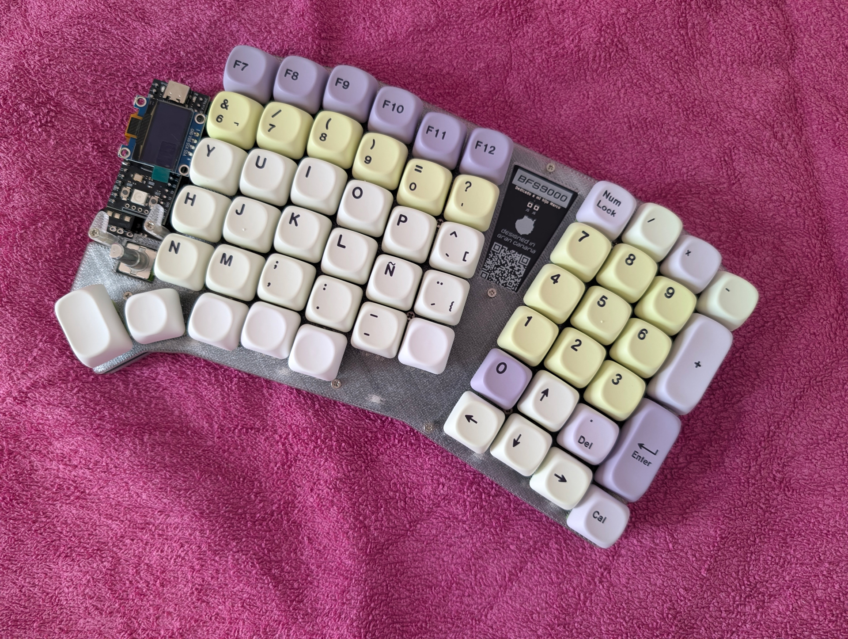
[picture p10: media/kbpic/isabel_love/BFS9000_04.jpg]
  
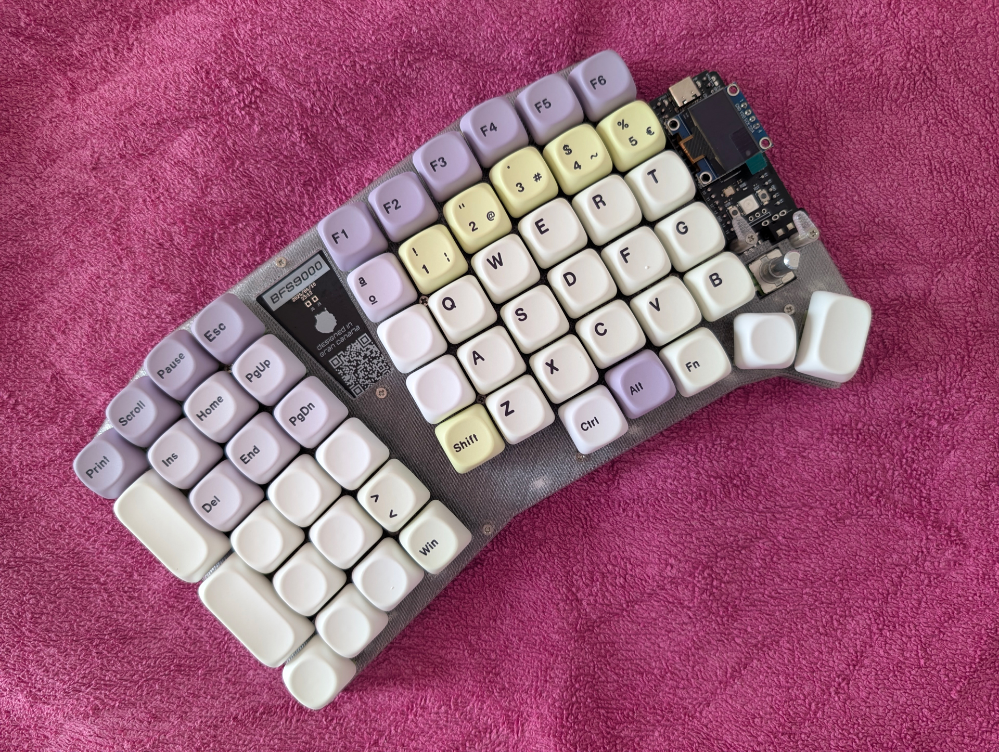
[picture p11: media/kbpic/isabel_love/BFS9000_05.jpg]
  
</p>

<p align="center">
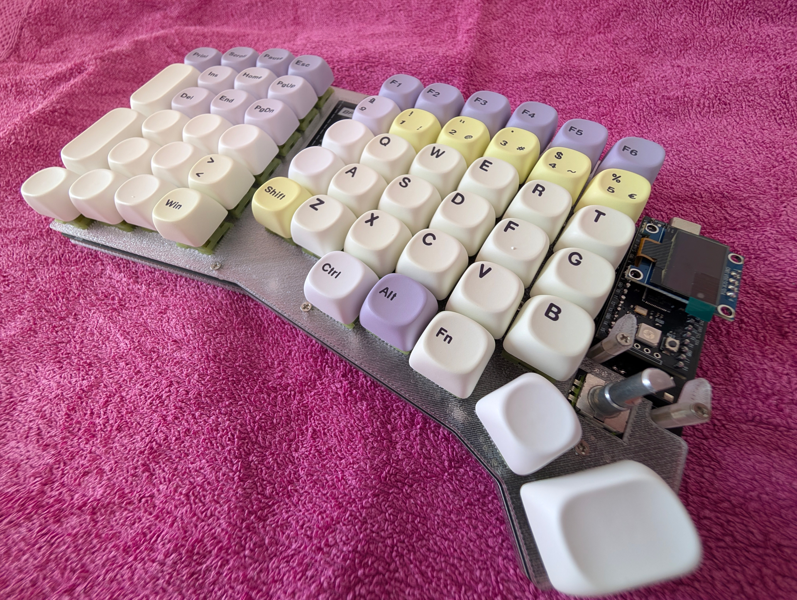
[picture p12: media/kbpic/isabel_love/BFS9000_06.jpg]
  
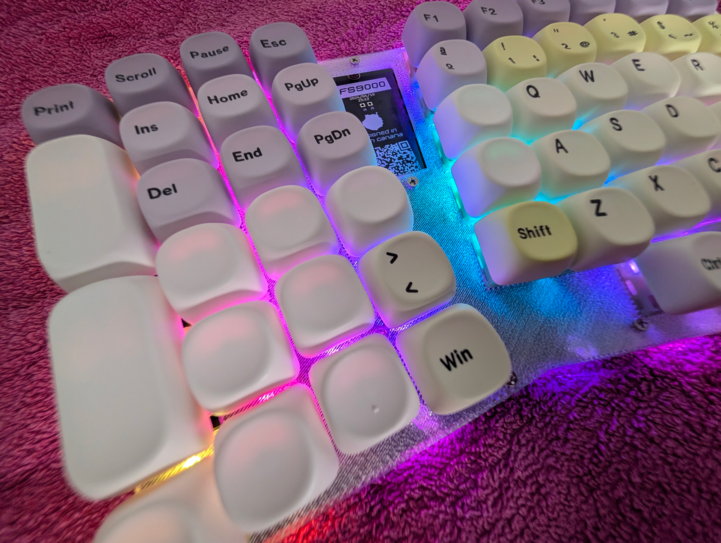
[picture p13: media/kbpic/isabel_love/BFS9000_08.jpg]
  
</p>

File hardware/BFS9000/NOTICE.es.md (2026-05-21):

# Avisos y atribución

Este proyecto de hardware contiene trabajo original de BFS9000, además de ficheros, ideas, referencias o trabajo derivado de otros proyectos de teclados open-source y librerías de componentes.

## BFS9000

- Proyecto: BFS9000
- Repositorio: https://github.com/jguillen-lab/BFS9000
- Copyright: 2026 jguillen-lab
- Licencia: MIT, salvo que se indique lo contrario en un fichero o directorio más específico.

## Sofle / SofleKeyboard

BFS9000 está basado en la familia de teclados Sofle.

- Proyecto: SofleKeyboard
- Autor original: Josef Adamcík
- Repositorio: https://github.com/josefadamcik/SofleKeyboard
- Licencia de hardware: MIT

## Sofle-Pico

Varios recursos de hardware, ideas de distribución, recursos de KiCad, huellas y referencias a modelos 3D de este directorio están basados en, copiados de o derivados de Sofle-Pico.

- Proyecto: Sofle-Pico
- Autor / mantenedor: JellyTitan
- Repositorio: https://github.com/JellyTitan/Sofle-Pico
- Web / documentación: https://www.soflepico.com/
- Licencia: MIT

## BFO-9000 / Keebio

El concepto de BFS9000 también toma inspiración de distribución del BFO-9000.

- Proyecto: BFO-9000
- Autor / proveedor: Keebio
- Documentación: https://docs.keeb.io/bfo-9000-build-guide
- Repositorio PCB: https://github.com/keebio/bfo9000-pcb
- Licencia: MIT

## Librerías KiCad y huellas generadas

Algunos símbolos, huellas, referencias a modelos 3D y geometría generada están basados en convenciones de librerías KiCad, librerías estándar de KiCad o salida del generador de huellas de KiCad.

- Proyecto: KiCad Libraries
- Web: https://www.kicad.org/libraries/
- Repositorio: https://gitlab.com/kicad/libraries
- Licencia: licencia de librerías KiCad / términos aplicables de las librerías KiCad

## Referencias a componentes y proveedores

Las referencias a Cherry MX, Kailh, SK6803 / SK6812, Raspberry Pi Pico, SSD1306, Pimoroni y otros nombres de componentes se usan únicamente para identificar piezas compatibles, huellas, modelos o números de pieza de fabricante. Las marcas comerciales siguen siendo propiedad de sus respectivos titulares.

## Notas

Este aviso pretende conservar la atribución de proyectos upstream y recursos de terceros. Si un fichero de este directorio tiene un aviso de licencia o atribución más específico, ese aviso prevalece para ese fichero.

> Esta traducción se ofrece como referencia. En caso de duda o conflicto, prevalece el texto
> original en inglés incluido en [NOTICE.md](NOTICE.md).

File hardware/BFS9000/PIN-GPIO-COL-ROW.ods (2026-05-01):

COLUMNA | GPIO | PIN | FILA | GPIO | PIN | Raspberry Pi RP2040 | QMK Firmware
0 | 1 | 2 | 0 | 9 | 12
1 | 2 | 4 | 1 | 10 | 14
2 | 3 | 5 | 2 | 11 | 15
3 | 4 | 6 | 3 | 12 | 16
4 | 5 | 7 | 4 | 13 | 17
5 | 8 | 11 | 5 | 26 | 31
6 | 27 | 32
7 | 19 | 25
8 | 20 | 26
9 | 21 | 27
10 | 22 | 29

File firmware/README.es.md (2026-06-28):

# BFS9000 Firmware

> 🇬🇧 **Prefer to read this in English?** → [README.md](README.md)

Firmware QMK + Vial para el teclado **BFS9000**.

Este directorio contiene tanto el árbol fuente del firmware como las versiones compiladas listas para flashear en el controlador RP2040.

## Estructura del directorio

```text
firmware/
├── README.md
├── README.es.md
├── releases/
│   ├── jguillen_lab_bfs9000_vial_v0.1.0.elf
│   └── jguillen_lab_bfs9000_vial_v0.1.0.uf2
└── vial-qmk/
    └── keyboards/
        └── jguillen_lab/
            └── bfs9000/
                ├── config.h
                ├── keyboard.json
                ├── readme.md
                ├── rules.mk
                └── keymaps/
                    ├── default/
                    │   └── keymap.c
                    └── vial/
                        ├── config.h
                        ├── keymap.c
                        ├── kle_raw.json
                        ├── rules.mk
                        └── vial.json
```

## Carpetas principales

### `releases/`

Contiene las versiones publicadas del firmware.

Archivos actuales:

```text
jguillen_lab_bfs9000_vial_v0.1.0.uf2
jguillen_lab_bfs9000_vial_v0.1.0.elf
```

El archivo `.uf2` es el que normalmente se usa para flashear el controlador RP2040.

El archivo `.elf` se conserva como artefacto de depuración/compilación. Puede ser útil para inspección de símbolos, análisis de tamaño o depuración, pero no es necesario para flashear el teclado en uso normal.

Esta carpeta debe contener solo artefactos finales de release. No debe contener temporales, objetos intermedios ni carpetas de compilación.

### `vial-qmk/`

Contiene el árbol fuente de firmware basado en QMK/Vial.

La definición principal del teclado está en:

```text
vial-qmk/keyboards/jguillen_lab/bfs9000/
```

Archivos importantes:

```text
config.h
keyboard.json
rules.mk
readme.md
```

El keymap principal de Vial está en:

```text
vial-qmk/keyboards/jguillen_lab/bfs9000/keymaps/vial/
```

Archivos importantes del keymap Vial:

```text
config.h
keymap.c
kle_raw.json
rules.mk
vial.json
```

## Compilación

Desde el directorio `vial-qmk/`:

```bash
qmk compile -kb jguillen_lab/bfs9000 -km vial
```

El firmware generado para RP2040 será un archivo `.uf2`.

## Flasheo

1. Pon el controlador RP2040 en modo bootloader.
2. Aparecerá como una unidad USB.
3. Copia el archivo `.uf2` de `releases/` a la unidad del RP2040.
4. El controlador se reiniciará automáticamente con el nuevo firmware.

Archivo recomendado para flashear la versión actual:

```text
releases/jguillen_lab_bfs9000_vial_v0.1.0.uf2
```

## Versionado

Las versiones publicadas del firmware usan este formato:

```text
vMAJOR.MINOR.PATCH
```

Ejemplo:

```text
v0.1.0
```

Criterio recomendado:

```text
v0.1.1  → correcciones pequeñas
v0.2.0  → cambios funcionales
v1.0.0  → primera versión estable
```

La versión publicada del firmware es independiente de la revisión de hardware de la PCB.

Distinción recomendada:

```text
Firmware release: v0.1.0
Hardware revision: rev0.4
```

En `keyboard.json`, el campo `usb.device_version` debe usar tres partes numéricas, por ejemplo:

```json
"device_version": "0.4.0"
```

## Qué se debe guardar

Guardar:

```text
releases/*.uf2
releases/*.elf
vial-qmk/keyboards/jguillen_lab/bfs9000/
```

No guardar:

```text
.build/
compiled/
obj_*/
*.o
*.d
*.a
*.tmp
```

Los objetos intermedios de compilación pueden regenerarse en cualquier momento y no deben formar parte de una release.

## Keymap principal

El keymap mantenido para uso normal con Vial es:

```text
vial-qmk/keyboards/jguillen_lab/bfs9000/keymaps/vial/keymap.c
```

Este keymap contiene el comportamiento personalizado del BFS9000 y debe considerarse la fuente principal usada para las releases publicadas.

## Notas

* Firmware basado en QMK + Vial.
* Controlador objetivo: RP2040.
* Las builds publicadas se guardan como archivos `.uf2`.
* El directorio `releases/` debe contener solo artefactos finales.

## Keymap personal de Vial

En la raíz de este directorio `firmware/` hay un fichero llamado:

```text
jguillen.vil
```

Este fichero contiene el keymap de Vial que uso actualmente.

Se puede cargar en el teclado utilizando la **aplicación de escritorio de Vial** o la **aplicación web de Vial**.

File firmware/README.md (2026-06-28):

# BFS9000 Firmware

> 🇪🇸 **¿Prefieres leer esto en español?** → [README.es.md](README.es.md)

QMK + Vial firmware for the **BFS9000** keyboard.

This directory contains both the firmware source tree and the compiled firmware releases ready to flash on the RP2040 controller.

## Directory structure

```text
firmware/
├── README.md
├── README.es.md
├── releases/
│   ├── jguillen_lab_bfs9000_vial_v0.1.0.elf
│   └── jguillen_lab_bfs9000_vial_v0.1.0.uf2
└── vial-qmk/
    └── keyboards/
        └── jguillen_lab/
            └── bfs9000/
                ├── config.h
                ├── keyboard.json
                ├── readme.md
                ├── rules.mk
                └── keymaps/
                    ├── default/
                    │   └── keymap.c
                    └── vial/
                        ├── config.h
                        ├── keymap.c
                        ├── kle_raw.json
                        ├── rules.mk
                        └── vial.json
```

## Main folders

### `releases/`

Contains published firmware builds.

Current release files:

```text
jguillen_lab_bfs9000_vial_v0.1.0.uf2
jguillen_lab_bfs9000_vial_v0.1.0.elf
```

The `.uf2` file is the one normally used to flash the RP2040 controller.

The `.elf` file is kept as a debug/build artefact. It can be useful for symbol inspection, size analysis or debugging, but it is not needed for normal flashing.

This folder should only contain final release artefacts. It should not contain temporary files, object files or build directories.

### `vial-qmk/`

Contains the QMK/Vial firmware source tree.

The main keyboard definition is located at:

```text
vial-qmk/keyboards/jguillen_lab/bfs9000/
```

Important files:

```text
config.h
keyboard.json
rules.mk
readme.md
```

The main Vial keymap is located at:

```text
vial-qmk/keyboards/jguillen_lab/bfs9000/keymaps/vial/
```

Important Vial keymap files:

```text
config.h
keymap.c
kle_raw.json
rules.mk
vial.json
```

## Build

From the `vial-qmk/` directory:

```bash
qmk compile -kb jguillen_lab/bfs9000 -km vial
```

The generated RP2040 firmware will be a `.uf2` file.

## Flashing

1. Put the RP2040 controller into bootloader mode.
2. It will appear as a USB mass-storage drive.
3. Copy the `.uf2` file from `releases/` to the RP2040 drive.
4. The controller will reboot automatically with the new firmware.

Recommended file for the current release:

```text
releases/jguillen_lab_bfs9000_vial_v0.1.0.uf2
```

## Versioning

Published firmware releases use this format:

```text
vMAJOR.MINOR.PATCH
```

Example:

```text
v0.1.0
```

Recommended meaning:

```text
v0.1.1  → small fixes
v0.2.0  → functional changes
v1.0.0  → first stable version
```

Firmware release versions are independent from the PCB hardware revision.

Recommended distinction:

```text
Firmware release: v0.1.0
Hardware revision: rev0.4
```

In `keyboard.json`, the `usb.device_version` field must use three numeric parts, for example:

```json
"device_version": "0.4.0"
```

## What should be kept

Keep:

```text
releases/*.uf2
releases/*.elf
vial-qmk/keyboards/jguillen_lab/bfs9000/
```

Do not keep:

```text
.build/
compiled/
obj_*/
*.o
*.d
*.a
*.tmp
```

Build intermediates can be regenerated at any time and should not be part of a release.

## Main keymap

The maintained keymap for normal Vial use is:

```text
vial-qmk/keyboards/jguillen_lab/bfs9000/keymaps/vial/keymap.c
```

This keymap contains the BFS9000 custom behaviour and should be considered the main source used for published firmware releases.

## Notes

* Firmware based on QMK + Vial.
* Target controller: RP2040.
* Published builds are stored as `.uf2` files.
* The `releases/` directory should contain final artefacts only.

## Personal Vial keymap

The root of this `firmware/` directory includes a file named:

```text
jguillen.vil
```

This file contains the Vial keymap currently used by me.

It can be loaded onto the keyboard using either the **Vial desktop application** or the **Vial web application**.

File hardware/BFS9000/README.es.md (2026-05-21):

# BFS9000 — Hardware

> 🇪🇳 **Prefer to read this in English?** ? [README.md](README.md)

Directorio de hardware del teclado **BFS9000**.

> **Trabajo en curso**
>
> Este hardware está actualmente en desarrollo activo y **todavía no es funcional**.
> La versión `0.4` debe considerarse un prototipo temprano, pensado solo para validación e iteración.
>
> **No** debes considerar el diseño actual, la PCB, los esquemáticos, las huellas, la BOM ni la documentación como algo final o listo para producción.
> Cabe esperar cambios incompatibles, funciones ausentes, errores de diseño y documentación incompleta.

## Estado

- Versión actual: `0.4`
- Fase de desarrollo: prototipo / WIP
- Estado funcional: **todavía no funciona**

## Notas

Este directorio está pensado para seguir el desarrollo en curso del hardware BFS9000.
En esta fase, el proyecto sigue evolucionando y es de esperar que haya cambios importantes antes de que llegue a ser utilizable.

## Licencia y atribución

Este directorio de hardware se publica bajo licencia MIT salvo que se indique lo contrario.

BFS9000 contiene trabajo original, además de ficheros, ideas, referencias o trabajo derivado de otros proyectos de teclados open-source y librerías de componentes.

Consulta:

- [LICENSE.es.md](LICENSE.es.md)
- [NOTICE.es.md](NOTICE.es.md)

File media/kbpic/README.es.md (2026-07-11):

# Galería de la comunidad — cómo añadir tu montaje

> 🇬🇧 **Prefer to read this in English?** → [README.md](README.md)

¡Gracias por querer compartir tu montaje de BFS9000! Así es como se hace:

1. Crea una carpeta con tu nombre (o alias) dentro de `media/kbpic/`:

   ```
   media/kbpic/<tu-nombre>/
   ```

2. Añade tus fotos dentro de esa carpeta (JPG o PNG, a ser posible de pocos MB cada una). Puedes nombrarlas como quieras, por ejemplo `01.jpg`, `02.jpg`...

3. Copia el archivo [`_template/README.es.md`](_template/README.es.md) dentro de tu carpeta y rellénalo con tus fotos y una nota breve sobre tu montaje.

4. Añade tu montaje a la galería completa, [`media/GALLERY.es.md`](../GALLERY.es.md) (o [`media/GALLERY.md`](../GALLERY.md), si prefieres escribir el pie de foto en inglés), usando esta plantilla:

   ```markdown
   ## Tu Nombre

   <p align="center">
     <img src="kbpic/<tu-nombre>/01.jpg" width="32%">
     <img src="kbpic/<tu-nombre>/02.jpg" width="32%">
     <img src="kbpic/<tu-nombre>/03.jpg" width="32%">
   </p>

   [Ver todas las fotos →](kbpic/<tu-nombre>/README.es.md)
   ```

   Cambia el nombre de la carpeta, las rutas de las imágenes y tu nombre. Si quieres, añade también un enlace a tu GitHub o redes junto a tu nombre.

5. Si además quieres que tu montaje aparezca como destacado en el [`README.es.md`](../../README.es.md) principal, añade también una pequeña entrada en el apartado **Galería de la comunidad** de ahí — con una foto o dos es suficiente, el conjunto completo va en la galería.

6. Abre una pull request con tus fotos nuevas y los cambios en el README.

¡Eso es todo — gracias por participar!

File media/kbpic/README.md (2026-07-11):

# Community gallery — how to add your build

> 🇪🇸 **¿Prefieres leer esto en español?** → [README.es.md](README.es.md)

Thanks for wanting to share your BFS9000 build! Here's how:

1. Create a folder with your name (or handle) under `media/kbpic/`:

   ```
   media/kbpic/<your-name>/
   ```

2. Add your photos inside it (JPG or PNG, ideally a few MB or less each). Name them however you like, for example `01.jpg`, `02.jpg`...

3. Copy the [`_template/README.md`](_template/README.md) file into your folder and fill it in with your photos and a short note about your build.

4. Add your build to the full gallery, [`media/GALLERY.md`](../GALLERY.md) (or [`media/GALLERY.es.md`](../GALLERY.es.md), if you'd rather write your caption in Spanish), using this template:

   ```markdown
   ## Your Name

   <p align="center">
     <img src="kbpic/<your-name>/01.jpg" width="32%">
     <img src="kbpic/<your-name>/02.jpg" width="32%">
     <img src="kbpic/<your-name>/03.jpg" width="32%">
   </p>

   [See all photos →](kbpic/<your-name>/README.md)
   ```

   Replace the folder name, image paths and your name. If you'd like, add a link to your GitHub or socials next to your name too.

5. If you'd like your build to also appear as a highlight on the main [`README.md`](../../README.md), add a small entry to the **Community builds** teaser there as well — keep it to a photo or two, the full set belongs in the gallery.

6. Open a pull request with your new photos and the README changes.

That's it — thanks for contributing!

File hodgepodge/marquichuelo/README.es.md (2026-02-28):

# Marquichuelo — Chuleta `hidapitester` (VialRGB por USB)

> 🇬🇧 **Prefer to read this in English?** → [README.md](README.md)

Esta guía te permite controlar y consultar el estado de la iluminación **VialRGB** del teclado **Marquichuelo** desde Windows usando **hidapitester** (HIDAPI), **sin tocar firmware**.

## Datos confirmados (del firmware)

- **VIAL_RAW_EPSIZE = 32** (payload real)
- En Windows con HIDAPI/hidapitester se envían **33 bytes**: `ReportID=0` + `32 bytes payload`
- Interfaz RAW HID de VIA/Vial:
  - `usagePage = 0xFF60`
  - `usage = 0x0061`
- IDs VIA:
  - `id_lighting_set_value = 0x07`
  - `id_lighting_get_value = 0x08`
- Subcomandos VialRGB:
  - `vialrgb_get_info = 0x40`
  - `vialrgb_get_mode = 0x41`
  - `vialrgb_get_supported = 0x42`
  - `vialrgb_get_number_leds = 0x43`
  - `vialrgb_get_led_info = 0x44`
  - `vialrgb_set_mode = 0x41`
  - `vialrgb_direct_fastset = 0x42` *(solo si el build trae `VIALRGB_DIRECT`)*
- Efectos VialRGB (por orden en `vialrgb_effects.inc`):
  - `OFF = 0`
  - `DIRECT = 1`
  - `SOLID_COLOR = 2`
  - *(el resto continúan en orden, sin reordenar)*

---

## 1) Listar dispositivos y localizar el interfaz RAW HID

Desde `C:\Users\jguillen\vial-qmk`:

```bat
.\hidapitester.exe --vidpid FEED/0000 --list-detail
```

Busca la entrada con:

- `usagePage: 0xFF60`
- `usage: 0x0061`
- `interface: 1`

---

## 2) Plantilla base de comandos

Recomendación: usa siempre filtros por VID/PID **y** `usagePage/usage` para asegurar que abre el interfaz correcto.

- `-l 33` → report de 33 bytes (ReportID + 32 payload)
- `-t 500` → timeout lectura 500 ms

---

## 3) Leer info (versión protocolo + brillo máximo)

**GET_INFO (0x40)**

```bat
.\hidapitester.exe --vidpid FEED/0000 --usagePage 0xFF60 --usage 0x61 -l 33 -t 500 ^
  --open --send-output 0,8,64 --read-input 0 --close
```

Interpretación de respuesta (`08 40 ...`):

- `08` = get_value
- `40` = get_info
- `01 00` = `protocol_version = 1` (little-endian)
- `FF` = `RGB_MATRIX_MAXIMUM_BRIGHTNESS = 255`

---

## 4) Leer estado (modo + speed + HSV)

**GET_MODE (0x41)**

```bat
.\hidapitester.exe --vidpid FEED/0000 --usagePage 0xFF60 --usage 0x61 -l 33 -t 500 ^
  --open --send-output 0,8,65 --read-input 0 --close
```

Respuesta (`08 41 ...`) y parseo:

- `mode_lo mode_hi` = modo (uint16 little-endian)
- `speed` = velocidad
- `hue` = H
- `sat` = S
- `val` = V (brillo)

Ejemplo real que viste:

- `08 41 02 00 FF 46 FF 1B ...`
  - modo = `0x0002` = **SOLID_COLOR**
  - speed = `0xFF` (255)
  - HSV = `(70, 255, 27)`

---

## 5) Apagar LEDs (modo OFF)

**SET_MODE (0x41), mode = 0**

```bat
.\hidapitester.exe --vidpid FEED/0000 --usagePage 0xFF60 --usage 0x61 -l 33 -t 500 ^
  --open --send-output 0,7,65,0,0,0,0,0,0 --read-input 0 --close
```

Payload explicado:

- `0` = ReportID
- `7` = set_value
- `65` (`0x41`) = set_mode
- `0,0` = modo OFF (uint16 little-endian)
- `0` = speed
- `0,0,0` = H,S,V (no importa en OFF)

---

## 6) Poner modo SOLID_COLOR y color (HSV)

**SET_MODE (0x41), mode = SOLID_COLOR = 2 → bytes `2,0`**

### Rojo (H=0 S=255 V=64)

```bat
.\hidapitester.exe --vidpid FEED/0000 --usagePage 0xFF60 --usage 0x61 -l 33 -t 500 ^
  --open --send-output 0,7,65,2,0,0,0,255,64 --read-input 0 --close
```

### Verde (H≈85 S=255 V=128)

```bat
.\hidapitester.exe --vidpid FEED/0000 --usagePage 0xFF60 --usage 0x61 -l 33 -t 500 ^
  --open --send-output 0,7,65,2,0,0,85,255,128 --read-input 0 --close
```

### Azul (H≈170 S=255 V=128)

```bat
.\hidapitester.exe --vidpid FEED/0000 --usagePage 0xFF60 --usage 0x61 -l 33 -t 500 ^
  --open --send-output 0,7,65,2,0,0,170,255,128 --read-input 0 --close
```

### Blanco (S=0, V=200)

```bat
.\hidapitester.exe --vidpid FEED/0000 --usagePage 0xFF60 --usage 0x61 -l 33 -t 500 ^
  --open --send-output 0,7,65,2,0,0,0,0,200 --read-input 0 --close
```

> Nota: `speed` suele ser irrelevante en SOLID_COLOR, pero se almacena.

---

## 7) Cambiar brillo “solo” (recomendación práctica)

VialRGB no expone un comando “solo brillo”; se cambia con **SET_MODE**.

Flujo recomendado:

1. Ejecuta **GET_MODE**
2. Reenvía **SET_MODE** conservando `mode/speed/hue/sat` y cambiando solo `val`.

---

## 8) Modo DIRECT (si está disponible)

**SET_MODE → DIRECT = 1 → bytes `1,0`**

```bat
.\hidapitester.exe --vidpid FEED/0000 --usagePage 0xFF60 --usage 0x61 -l 33 -t 500 ^
  --open --send-output 0,7,65,1,0,0,0,255,64 --read-input 0 --close
```

---

## 9) Consultas extra (layout / flags)

### Número de LEDs

**GET_NUMBER_LEDS (0x43)**

```bat
.\hidapitester.exe --vidpid FEED/0000 --usagePage 0xFF60 --usage 0x61 -l 33 -t 500 ^
  --open --send-output 0,8,67 --read-input 0 --close
```

### Info de un LED (posición/flags, no color)

**GET_LED_INFO (0x44)** — LED index 0 (`0,0` little-endian)

```bat
.\hidapitester.exe --vidpid FEED/0000 --usagePage 0xFF60 --usage 0x61 -l 33 -t 500 ^
  --open --send-output 0,8,68,0,0 --read-input 0 --close
```

Para LED 2 sería `2,0`.

---

## 10) Comprobación rápida “cambio y verificación”

1) Poner rojo sólido:

```bat
.\hidapitester.exe --vidpid FEED/0000 --usagePage 0xFF60 --usage 0x61 -l 33 -t 500 ^
  --open --send-output 0,7,65,2,0,0,0,255,64 --read-input 0 --close
```

2) Leer estado:

```bat
.\hidapitester.exe --vidpid FEED/0000 --usagePage 0xFF60 --usage 0x61 -l 33 -t 500 ^
  --open --send-output 0,8,65 --read-input 0 --close
```

Deberías ver algo como:

- `08 41 02 00 00 00 FF 40 ...`
  - modo 2, speed 0, HSV (0,255,64)

---

## Apéndice: recordatorio de bytes

- `0` (primer byte que envías) = **ReportID** (Windows/hidapitester)
- `0x07` (`7`) = set lighting value
- `0x08` (`8`) = get lighting value
- `0x40` (`64`) = get_info
- `0x41` (`65`) = get_mode / set_mode
- `mode` es **uint16 little-endian**:
  - OFF = `0,0`
  - DIRECT = `1,0`
  - SOLID_COLOR = `2,0`

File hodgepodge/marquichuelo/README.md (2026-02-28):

# Marquichuelo — `hidapitester` cheat sheet (VialRGB over USB)

> 🇪🇸 **¿Prefieres leer esto en español?** → [README.es.md](README.es.md)

This guide lets you control and query **VialRGB** lighting on the **Marquichuelo** keyboard from Windows using **hidapitester** (HIDAPI), **without touching firmware**.

## Confirmed firmware facts

- **VIAL_RAW_EPSIZE = 32** (real payload)
- On Windows with HIDAPI/hidapitester you send **33 bytes**: `ReportID=0` + `32 bytes payload`
- VIA/Vial RAW HID interface:
  - `usagePage = 0xFF60`
  - `usage = 0x0061`
- VIA IDs:
  - `id_lighting_set_value = 0x07`
  - `id_lighting_get_value = 0x08`
- VialRGB subcommands:
  - `vialrgb_get_info = 0x40`
  - `vialrgb_get_mode = 0x41`
  - `vialrgb_get_supported = 0x42`
  - `vialrgb_get_number_leds = 0x43`
  - `vialrgb_get_led_info = 0x44`
  - `vialrgb_set_mode = 0x41`
  - `vialrgb_direct_fastset = 0x42` *(only if the build includes `VIALRGB_DIRECT`)*
- VialRGB effects (in `vialrgb_effects.inc` order):
  - `OFF = 0`
  - `DIRECT = 1`
  - `SOLID_COLOR = 2`
  - *(the rest continue in order, no reordering)*

---

## 1) List devices and locate the RAW HID interface

From `C:\Users\jguillen\vial-qmk`:

```bat
.\hidapitester.exe --vidpid FEED/0000 --list-detail
```

Look for the entry with:

- `usagePage: 0xFF60`
- `usage: 0x0061`
- `interface: 1`

---

## 2) Base command template

Recommendation: always filter by VID/PID **and** `usagePage/usage` to ensure you open the correct interface.

- `-l 33` → 33-byte report (ReportID + 32 payload)
- `-t 500` → 500 ms read timeout

---

## 3) Read info (protocol version + max brightness)

**GET_INFO (0x40)**

```bat
.\hidapitester.exe --vidpid FEED/0000 --usagePage 0xFF60 --usage 0x61 -l 33 -t 500 ^
  --open --send-output 0,8,64 --read-input 0 --close
```

Response interpretation (`08 40 ...`):

- `08` = get_value
- `40` = get_info
- `01 00` = `protocol_version = 1` (little-endian)
- `FF` = `RGB_MATRIX_MAXIMUM_BRIGHTNESS = 255`

---

## 4) Read state (mode + speed + HSV)

**GET_MODE (0x41)**

```bat
.\hidapitester.exe --vidpid FEED/0000 --usagePage 0xFF60 --usage 0x61 -l 33 -t 500 ^
  --open --send-output 0,8,65 --read-input 0 --close
```

Response (`08 41 ...`) parsing:

- `mode_lo mode_hi` = mode (uint16 little-endian)
- `speed` = speed
- `hue` = H
- `sat` = S
- `val` = V (brightness)

Real example you saw:

- `08 41 02 00 FF 46 FF 1B ...`
  - mode = `0x0002` = **SOLID_COLOR**
  - speed = `0xFF` (255)
  - HSV = `(70, 255, 27)`

---

## 5) Turn LEDs off (OFF mode)

**SET_MODE (0x41), mode = 0**

```bat
.\hidapitester.exe --vidpid FEED/0000 --usagePage 0xFF60 --usage 0x61 -l 33 -t 500 ^
  --open --send-output 0,7,65,0,0,0,0,0,0 --read-input 0 --close
```

Payload explained:

- `0` = ReportID
- `7` = set_value
- `65` (`0x41`) = set_mode
- `0,0` = OFF mode (uint16 little-endian)
- `0` = speed
- `0,0,0` = H,S,V (irrelevant for OFF)

---

## 6) Set SOLID_COLOR mode and colour (HSV)

**SET_MODE (0x41), mode = SOLID_COLOR = 2 → bytes `2,0`**

### Red (H=0 S=255 V=64)

```bat
.\hidapitester.exe --vidpid FEED/0000 --usagePage 0xFF60 --usage 0x61 -l 33 -t 500 ^
  --open --send-output 0,7,65,2,0,0,0,255,64 --read-input 0 --close
```

### Green (H≈85 S=255 V=128)

```bat
.\hidapitester.exe --vidpid FEED/0000 --usagePage 0xFF60 --usage 0x61 -l 33 -t 500 ^
  --open --send-output 0,7,65,2,0,0,85,255,128 --read-input 0 --close
```

### Blue (H≈170 S=255 V=128)

```bat
.\hidapitester.exe --vidpid FEED/0000 --usagePage 0xFF60 --usage 0x61 -l 33 -t 500 ^
  --open --send-output 0,7,65,2,0,0,170,255,128 --read-input 0 --close
```

### White (S=0, V=200)

```bat
.\hidapitester.exe --vidpid FEED/0000 --usagePage 0xFF60 --usage 0x61 -l 33 -t 500 ^
  --open --send-output 0,7,65,2,0,0,0,0,200 --read-input 0 --close
```

> Note: `speed` is often irrelevant for SOLID_COLOR, but it is stored.

---

## 7) Changing “brightness only” (practical recommendation)

VialRGB does not expose a “brightness only” command; brightness changes via **SET_MODE**.

Recommended flow:

1. Run **GET_MODE**
2. Re-send **SET_MODE** keeping `mode/speed/hue/sat` and changing only `val`.

---

## 8) DIRECT mode (if available)

**SET_MODE → DIRECT = 1 → bytes `1,0`**

```bat
.\hidapitester.exe --vidpid FEED/0000 --usagePage 0xFF60 --usage 0x61 -l 33 -t 500 ^
  --open --send-output 0,7,65,1,0,0,0,255,64 --read-input 0 --close
```

---

## 9) Extra queries (layout / flags)

### LED count

**GET_NUMBER_LEDS (0x43)**

```bat
.\hidapitester.exe --vidpid FEED/0000 --usagePage 0xFF60 --usage 0x61 -l 33 -t 500 ^
  --open --send-output 0,8,67 --read-input 0 --close
```

### LED info (position/flags, not colour)

**GET_LED_INFO (0x44)** — LED index 0 (`0,0` little-endian)

```bat
.\hidapitester.exe --vidpid FEED/0000 --usagePage 0xFF60 --usage 0x61 -l 33 -t 500 ^
  --open --send-output 0,8,68,0,0 --read-input 0 --close
```

For LED 2 you’d use `2,0`.

---

## 10) Quick “change and verify” check

1) Set solid red:

```bat
.\hidapitester.exe --vidpid FEED/0000 --usagePage 0xFF60 --usage 0x61 -l 33 -t 500 ^
  --open --send-output 0,7,65,2,0,0,0,255,64 --read-input 0 --close
```

2) Read state:

```bat
.\hidapitester.exe --vidpid FEED/0000 --usagePage 0xFF60 --usage 0x61 -l 33 -t 500 ^
  --open --send-output 0,8,65 --read-input 0 --close
```

You should see something like:

- `08 41 02 00 00 00 FF 40 ...`
  - mode 2, speed 0, HSV (0,255,64)

---

## Appendix: byte reminders

- `0` (first byte you send) = **ReportID** (Windows/hidapitester)
- `0x07` (`7`) = set lighting value
- `0x08` (`8`) = get lighting value
- `0x40` (`64`) = get_info
- `0x41` (`65`) = get_mode / set_mode
- `mode` is **uint16 little-endian**:
  - OFF = `0,0`
  - DIRECT = `1,0`
  - SOLID_COLOR = `2,0`

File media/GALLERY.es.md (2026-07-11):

# Galería de montajes de la comunidad

> 🇬🇧 **Prefer to read this in English?** → [GALLERY.md](GALLERY.md)

Todos los BFS9000 montados por la comunidad. ¿Quieres añadir el tuyo? Mira [`kbpic/README.es.md`](kbpic/README.es.md).

---

## Isabel Love

<p align="center">
  
</p>

[Ver todas las fotos →](kbpic/isabel_love/README.md)

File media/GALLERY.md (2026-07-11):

# Community builds gallery

> 🇪🇸 **¿Prefieres leer esto en español?** → [GALLERY.es.md](GALLERY.es.md)

Every BFS9000 built by the community. Want to add yours? See [`kbpic/README.md`](kbpic/README.md).

---

## Isabel Love

<p align="center">
  
</p>

[See all photos →](kbpic/isabel_love/README.md)

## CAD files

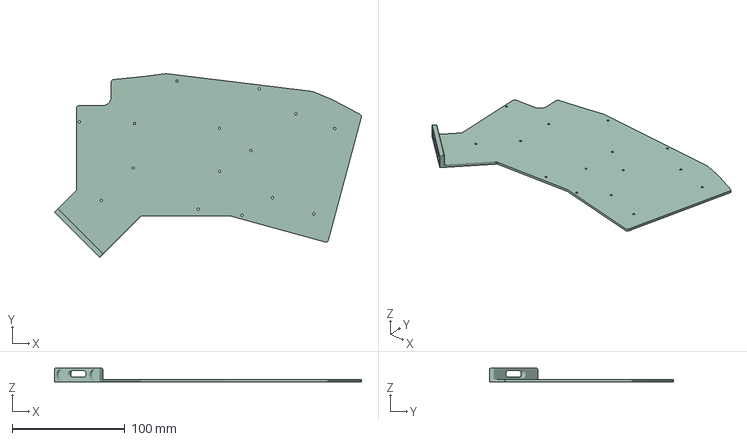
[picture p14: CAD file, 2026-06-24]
hardware/enclosures/rev0.4/B_BFS9000_full_bottom_tps65.3mf
271.9 x 162.8 x 12.0 mm

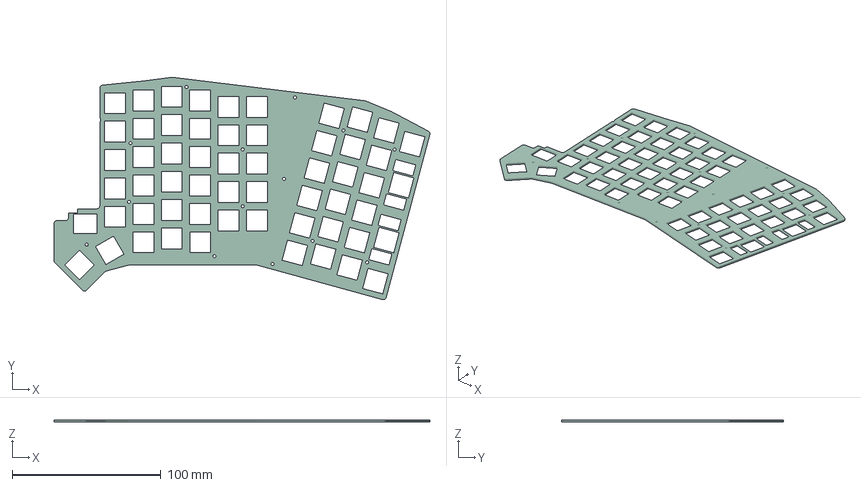
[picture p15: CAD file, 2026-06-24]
hardware/enclosures/rev0.4/B_BFS9000_full_switch.3mf
252.4 x 149.4 x 1.50 mm

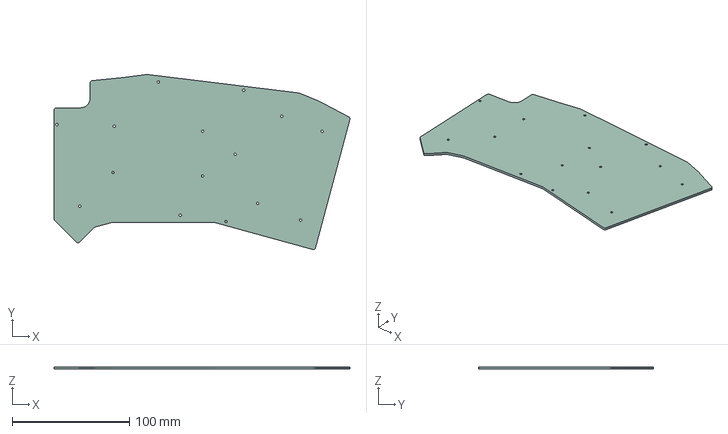
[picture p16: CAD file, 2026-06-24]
hardware/enclosures/rev0.4/C_BFS9000_full_with_window_bottom.3mf
252.5 x 149.4 x 2.00 mm

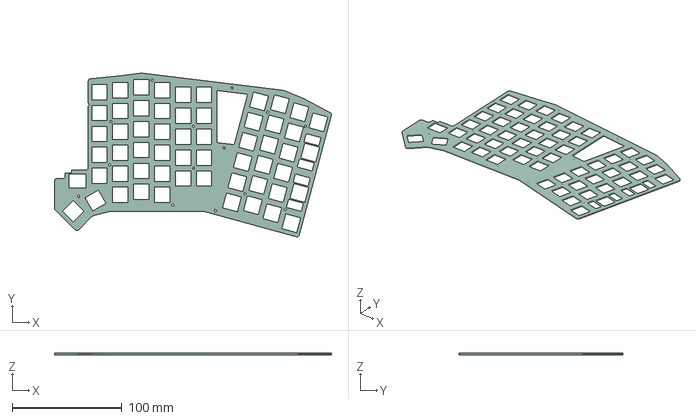
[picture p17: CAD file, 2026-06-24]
hardware/enclosures/rev0.4/C_BFS9000_full_with_window_switch.3mf
252.4 x 149.4 x 1.50 mm

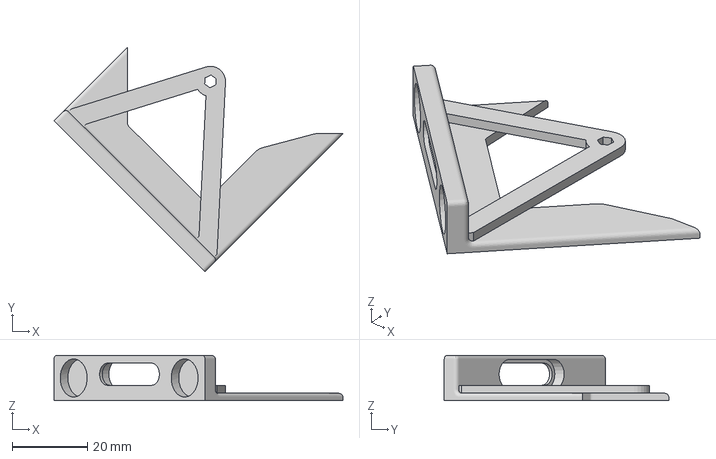
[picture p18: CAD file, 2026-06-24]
hardware/enclosures/rev0.4/X_tps65_main_bottom_addon.3mf
76.6 x 59.5 x 12.0 mm

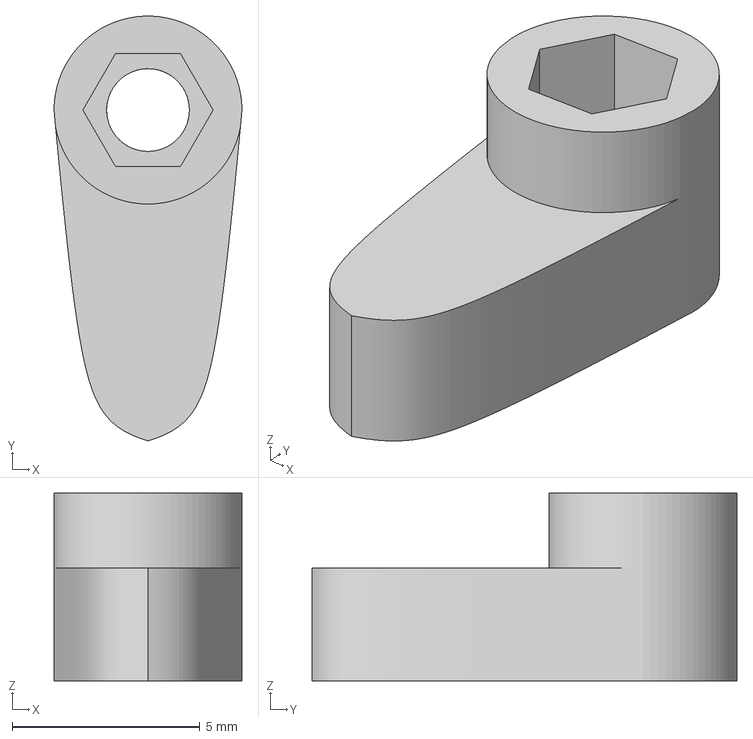
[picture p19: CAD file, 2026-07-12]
hardware/other/screen_protector_riser_top.3mf
5.00 x 11.3 x 5.00 mm

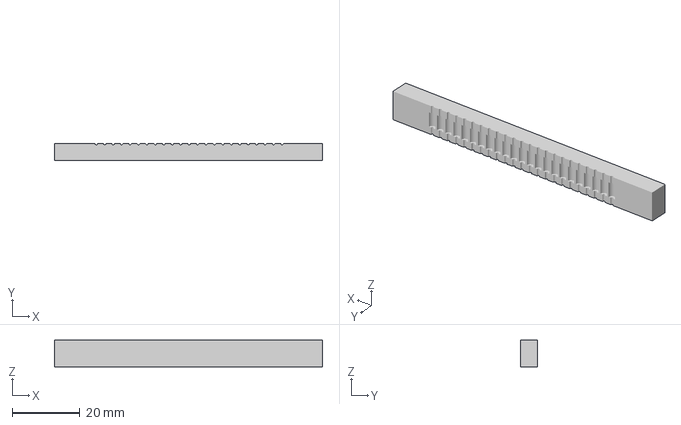
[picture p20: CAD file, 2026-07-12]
hardware/other/diode_leg_bender.3mf
79.4 x 5.00 x 7.90 mm

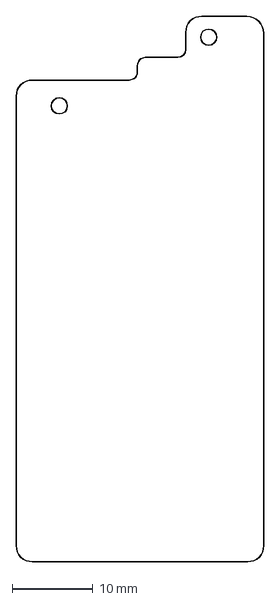
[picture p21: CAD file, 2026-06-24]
hardware/enclosures/rev0.4/CNC_screen.dxf
30.8 x 67.8 mm

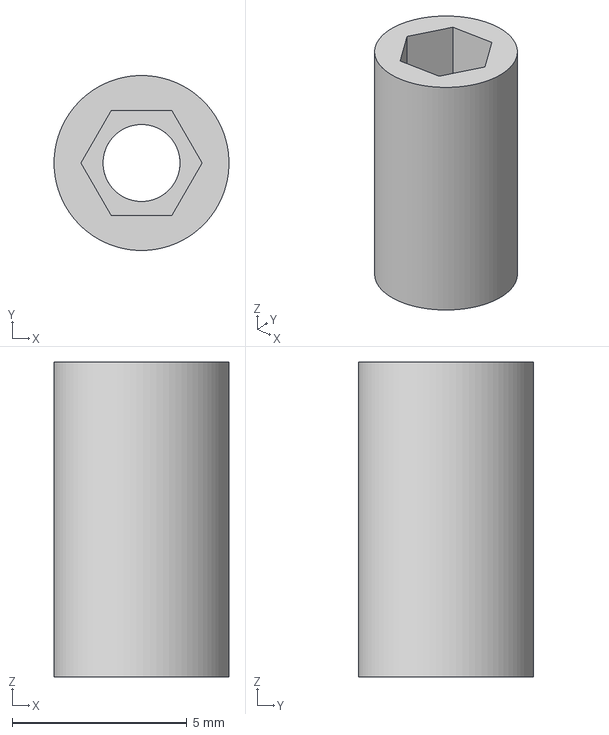
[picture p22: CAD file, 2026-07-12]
hardware/other/screen_protector_riser_bottom.3mf
5.00 x 5.00 x 9.00 mm

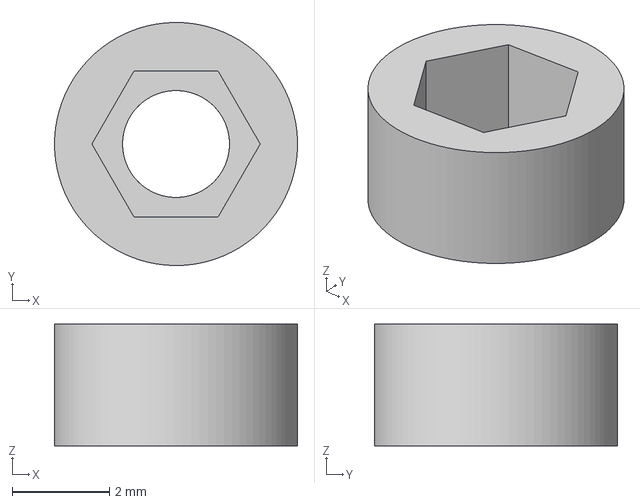
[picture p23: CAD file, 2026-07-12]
hardware/other/D31_spacer.3mf
5.00 x 5.00 x 2.50 mm

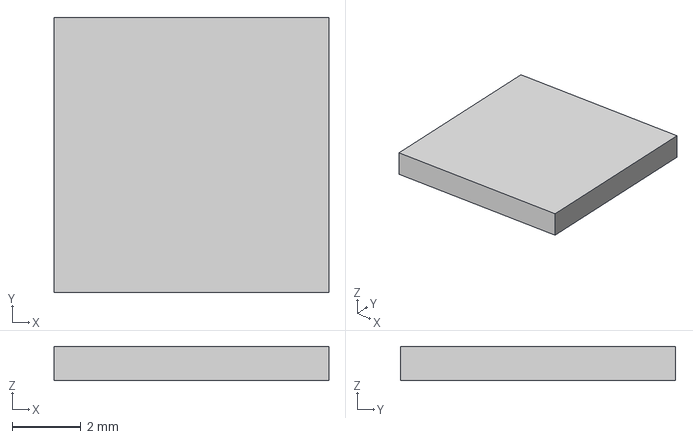
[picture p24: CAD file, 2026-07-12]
hardware/other/screen_spacer.3mf
8.00 x 8.00 x 1.00 mm

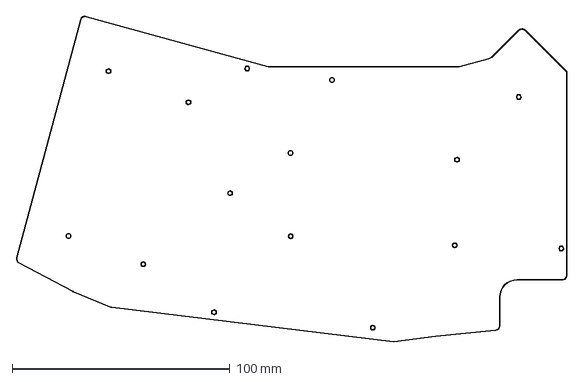
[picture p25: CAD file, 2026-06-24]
hardware/enclosures/rev0.4/CNC_bottom.dxf
252.6 x 149.4 mm

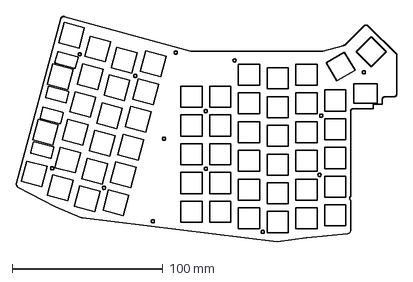
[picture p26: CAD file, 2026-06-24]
hardware/enclosures/rev0.4/CNC_switch.dxf
252.6 x 149.4 mm

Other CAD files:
hardware/enclosures/rev0.4/A_BFS9000_sectionable_bottom_tps65.3mf
hardware/enclosures/rev0.4/A_BFS9000_sectionable_switch.3mf
hardware/enclosures/rev0.4/A_BFS9000_sectionable_bottom.3mf
hardware/enclosures/rev0.4/X_tps65_bottom.3mf
hardware/enclosures/rev0.4/X_tps65_frame.3mf

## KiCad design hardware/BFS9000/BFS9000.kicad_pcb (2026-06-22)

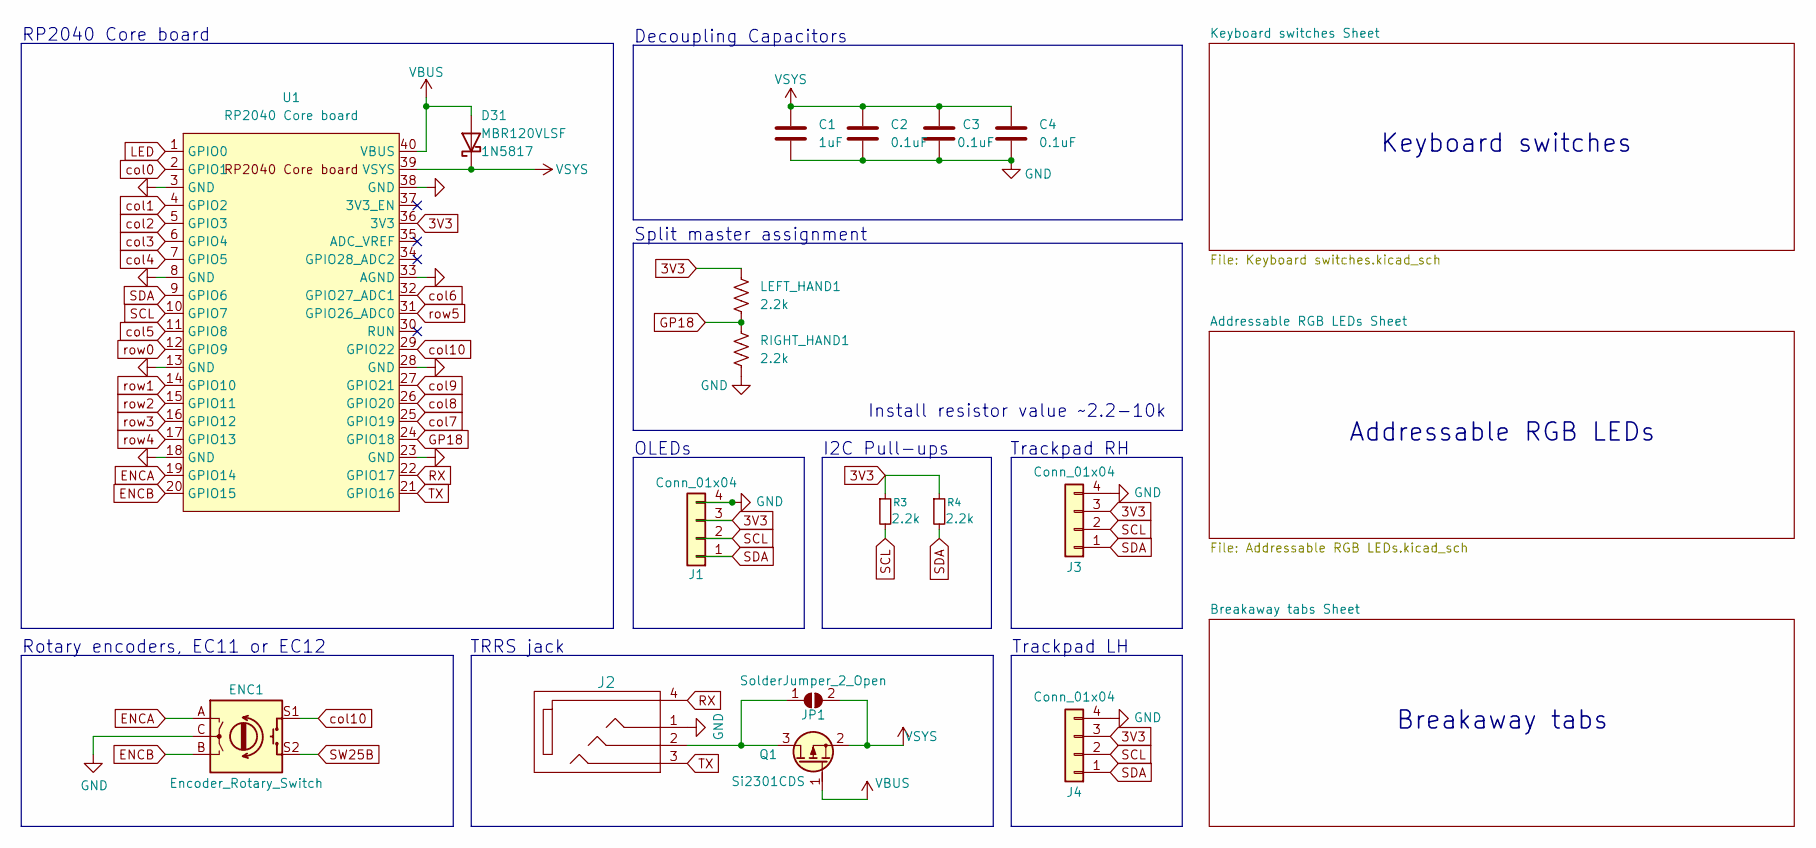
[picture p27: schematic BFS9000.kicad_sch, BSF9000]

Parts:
C1: 1uF; C_0805_HandSolder; Tolerance (%) 10; Voltage Rating 50V; MFG PN CL21B105KBFNNNE; JLCPCB_PN C28323
C2, C3, C4: 0.1uF; C_0805_HandSolder; Tolerance (%) 10; Voltage Rating 50V; MFG PN CC0805KRX7R9BB104; JLCPCB_PN C49678
D31: MBR120VLSF; D_Hybrid_SOD-123_DO-41_P7.62mm_DS
ENC1: Encoder_Rotary_Switch; Encoder_EC11E_Switch_Vertical_H20mm; MFG PN EC11E18244AU; JLCPCB_PN C202365
J1: Conn_01x04; Display_OLED_SSD1306_128x64; MFG PN DNP; JLCPCB_PN DNP
J2: MJ-4PP-9; MFG PN PJ-320AS; JLCPCB_PN C2939182
J3, J4: Conn_01x04; Conn_Touchpad; MFG PN DNP; JLCPCB_PN DNP
JP1: SolderJumper_2_Open; SolderJumper_Level_Shifter_Bypass; MFG PN DNP; JLCPCB_PN DNP
LEFT_HAND1: 2.2k; R_Hybrid_1206_P6.3mm; MFG PN CFR-25JB-52-2K2; JLCPCB_PN C1364486
Q1: Si2301CDS; SOT-23_DS; MFG PN SI2301CDS-T1-GE3; JLCPCB_PN C10487
R3, R4: 2.2k; R_Hybrid_1206_P6.3mm; MFG PN CFR-25JB-52-2K2; JLCPCB_PN C1364486
RIGHT_HAND1: 2.2k; R_Hybrid_1206_P6.3mm; MFG PN CFR-25JB-52-2K2; JLCPCB_PN C1364486
U1: RP2040 Core board; RPi_Pico_SMD_TH_DS; MFG PN DNP; JLCPCB_PN DNP

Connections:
3V3: J1.3, J3.3, J4.3, LEFT_HAND1.2, R3.1, R4.1, U1.36 (3V3)
ENCA: ENC1.A, U1.19 (GPIO14)
ENCB: ENC1.B, U1.20 (GPIO15)
GND: C1.2, C2.2, C3.2, C4.2, ENC1.C, J1.4, J2.1, J3.4, J4.4, RIGHT_HAND1.2, U1.3 (GND), U1.8 (GND), U1.13 (GND), U1.18 (GND), U1.23 (GND), U1.28 (GND), U1.33 (AGND), U1.38 (GND); also elsewhere on the board
GP18: LEFT_HAND1.1, RIGHT_HAND1.1, U1.24 (GPIO18)
LED: U1.1 (GPIO0); also elsewhere on the board
unnamed: J2.2, JP1.1 (A), Q1.3 (D)
RX: J2.4, U1.22 (GPIO17)
SCL: J1.2, J3.2, J4.2, R3.2, U1.10 (GPIO7)
SDA: J1.1, J3.1, J4.1, R4.2, U1.9 (GPIO6)
SW25B: ENC1.S2; also elsewhere on the board
TX: J2.3, U1.21 (GPIO16)
VBUS: D31.2 (A), Q1.1 (G), U1.40 (VBUS)
VSYS: C1.1, C2.1, C3.1, C4.1, D31.1 (K), JP1.2 (B), Q1.2 (S), U1.39 (VSYS); also elsewhere on the board
col0: U1.2 (GPIO1); also elsewhere on the board
col1: U1.4 (GPIO2); also elsewhere on the board
col2: U1.5 (GPIO3); also elsewhere on the board
col3: U1.6 (GPIO4); also elsewhere on the board
col4: U1.7 (GPIO5); also elsewhere on the board
col5: U1.11 (GPIO8); also elsewhere on the board
col6: U1.32 (GPIO27_ADC1); also elsewhere on the board
col7: U1.25 (GPIO19); also elsewhere on the board
col8: U1.26 (GPIO20); also elsewhere on the board
col9: U1.27 (GPIO21); also elsewhere on the board
col10: ENC1.S1, U1.29 (GPIO22); also elsewhere on the board
row0: U1.12 (GPIO9); also elsewhere on the board
row1: U1.14 (GPIO10); also elsewhere on the board
row2: U1.15 (GPIO11); also elsewhere on the board
row3: U1.16 (GPIO12); also elsewhere on the board
row4: U1.17 (GPIO13); also elsewhere on the board
row5: U1.31 (GPIO26_ADC0); also elsewhere on the board

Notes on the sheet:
Rotary encoders, EC11 or EC12
OLEDs
Install resistor value ~2.2-10k
Split master assignment
I2C Pull-ups
Breakaway tabs
TRRS jack
Keyboard switches
RP2040 Core board
Trackpad LH
Trackpad RH
Addressable RGB LEDs
Decoupling Capacitors

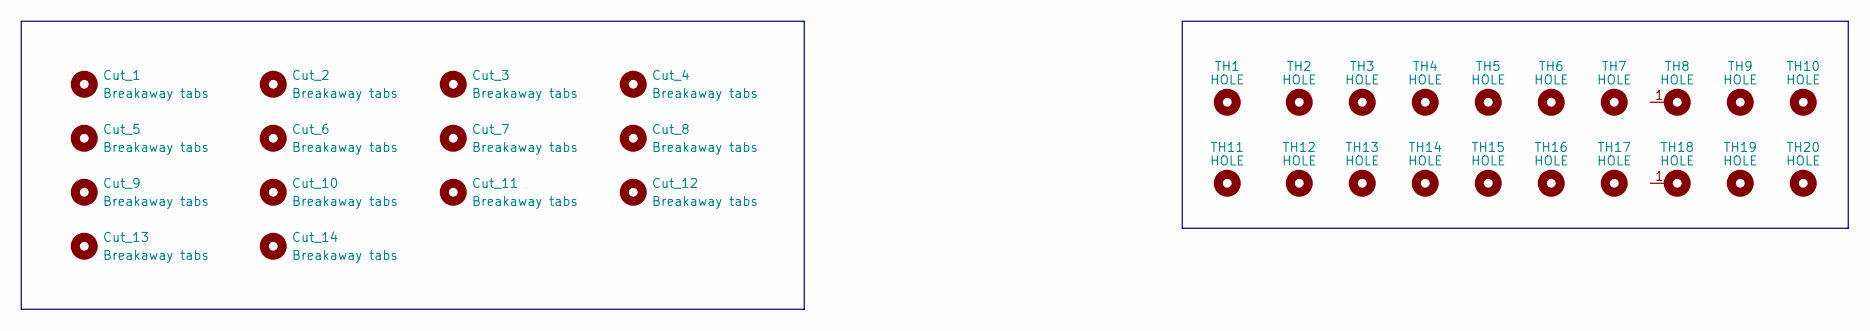
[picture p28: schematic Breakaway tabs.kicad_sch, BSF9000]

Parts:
Cut_1, Cut_2, Cut_3, Cut_4, Cut_5, Cut_6, Cut_7, Cut_8, Cut_9, Cut_10, Cut_11, Cut_12, Cut_13, Cut_14: Breakaway tabs; Cutout_Long_Oval; MFR.Part # DNP; JLCPCB Part # DNP
TH1, TH2, TH4, TH5: HOLE; Mount_M2_Post_Hole_Keyplate_Narrow; MFG PN DNP; JLCPCB_PN DNP
TH3, TH6, TH7, TH9, TH10, TH11, TH12, TH13, TH14, TH15, TH16, TH17, TH19, TH20: HOLE; Mount_M2_Post_Hole_Keyplate_Wide; MFG PN DNP; JLCPCB_PN DNP
TH8, TH18: HOLE; Mount_Tenting_Puck; MFG PN DNP; JLCPCB_PN DNP

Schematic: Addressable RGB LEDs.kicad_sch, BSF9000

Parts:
J5, J6: Conn_01x01; PinHeader_1x01_P2.54mm; MFG PN DNP; JLCPCB_PN DNP
MLED1, MLED2, MLED3, MLED4, MLED5, MLED6, MLED7, MLED8, MLED9, MLED10, MLED11, MLED12, MLED13, MLED14, MLED15, MLED16, MLED17, MLED18, MLED19, MLED20, MLED21, MLED22, MLED23, MLED24, MLED25, MLED26, MLED27, MLED28, MLED29: SK6803 MINI-E; Cust_SK6803_MINI-E_BFS9000; MFG PN SK6803MINI-E-001; JLCPCB_PN C5242955
MULED1, MULED2, MULED3: SK6803 MINI-E; Cust_SK6803_MINI-E_BFS9000_Underglow; MFG PN SK6803MINI-E-001; JLCPCB_PN C5242955
SLED1, SLED2, SLED3, SLED4, SLED5, SLED6, SLED7, SLED8, SLED9, SLED10, SLED11, SLED12, SLED13, SLED14, SLED15, SLED16, SLED17, SLED18, SLED19, SLED20, SLED21, SLED22: SK6803 MINI-E; Cust_SK6803_MINI-E_BFS9000; MFG PN SK6803MINI-E-001; JLCPCB_PN C5242955
SULED1, SULED2: SK6803 MINI-E; Cust_SK6803_MINI-E_BFS9000_Underglow; MFG PN SK6803MINI-E-001; JLCPCB_PN C5242955
TLED1, TLED2, TLED3, TLED4, TLED5, TLED6: SK6803 MINI-E; Cust_SK6803_MINI-E_BFS9000; MFG PN SK6803MINI-E-001; JLCPCB_PN C5242955

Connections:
GND: MLED1.1 (GND), MLED2.1 (GND), MLED3.1 (GND), MLED4.1 (GND), MLED5.1 (GND), MLED6.1 (GND), MLED7.1 (GND), MLED8.1 (GND), MLED9.1 (GND), MLED10.1 (GND), MLED11.1 (GND), MLED12.1 (GND), MLED13.1 (GND), MLED14.1 (GND), MLED15.1 (GND), MLED16.1 (GND), MLED17.1 (GND), MLED18.1 (GND), MLED19.1 (GND), MLED20.1 (GND), MLED21.1 (GND), MLED22.1 (GND), MLED23.1 (GND), MLED24.1 (GND), MLED25.1 (GND), MLED26.1 (GND), MLED27.1 (GND), MLED28.1 (GND), MLED29.1 (GND), MULED1.1 (GND), MULED2.1 (GND), MULED3.1 (GND), SLED1.1 (GND), SLED2.1 (GND), SLED3.1 (GND), SLED4.1 (GND), SLED5.1 (GND), SLED6.1 (GND), SLED7.1 (GND), SLED8.1 (GND), SLED9.1 (GND), SLED10.1 (GND), SLED11.1 (GND), SLED12.1 (GND), SLED13.1 (GND), SLED14.1 (GND), SLED15.1 (GND), SLED16.1 (GND), SLED17.1 (GND), SLED18.1 (GND), SLED19.1 (GND), SLED20.1 (GND), SLED21.1 (GND), SLED22.1 (GND), SULED1.1 (GND), SULED2.1 (GND), TLED1.1 (GND), TLED2.1 (GND), TLED3.1 (GND), TLED4.1 (GND), TLED5.1 (GND), TLED6.1 (GND); also elsewhere on the board
LED: MLED1.2 (DIN); also elsewhere on the board
LED_N: J6.1 (Pin_1_1), SLED1.2 (DIN), TLED6.4 (DOUT)
LED_T: J5.1 (Pin_1_1), MULED3.4 (DOUT), TLED1.2 (DIN)
LED_U: MLED29.4 (DOUT), MULED1.2 (DIN)
unnamed: MLED1.4 (DOUT), MLED2.2 (DIN)
unnamed: MLED2.4 (DOUT), MLED3.2 (DIN)
unnamed: MLED3.4 (DOUT), MLED4.2 (DIN)
unnamed: MLED4.4 (DOUT), MLED5.2 (DIN)
unnamed: MLED5.4 (DOUT), MLED6.2 (DIN)
unnamed: MLED6.4 (DOUT), MLED7.2 (DIN)
unnamed: MLED7.4 (DOUT), MLED8.2 (DIN)
unnamed: MLED8.4 (DOUT), MLED9.2 (DIN)
unnamed: MLED9.4 (DOUT), MLED10.2 (DIN)
unnamed: MLED10.4 (DOUT), MLED11.2 (DIN)
unnamed: MLED11.4 (DOUT), MLED12.2 (DIN)
unnamed: MLED12.4 (DOUT), MLED13.2 (DIN)
unnamed: MLED13.4 (DOUT), MLED14.2 (DIN)
unnamed: MLED14.4 (DOUT), MLED15.2 (DIN)
unnamed: MLED15.4 (DOUT), MLED16.2 (DIN)
unnamed: MLED16.4 (DOUT), MLED17.2 (DIN)
unnamed: MLED17.4 (DOUT), MLED18.2 (DIN)
unnamed: MLED18.4 (DOUT), MLED19.2 (DIN)
unnamed: MLED19.4 (DOUT), MLED20.2 (DIN)
unnamed: MLED20.4 (DOUT), MLED21.2 (DIN)
unnamed: MLED21.4 (DOUT), MLED22.2 (DIN)
unnamed: MLED22.4 (DOUT), MLED23.2 (DIN)
unnamed: MLED23.4 (DOUT), MLED24.2 (DIN)
unnamed: MLED24.4 (DOUT), MLED25.2 (DIN)
unnamed: MLED25.4 (DOUT), MLED26.2 (DIN)
unnamed: MLED26.4 (DOUT), MLED27.2 (DIN)
unnamed: MLED27.4 (DOUT), MLED28.2 (DIN)
unnamed: MLED28.4 (DOUT), MLED29.2 (DIN)
unnamed: MULED1.4 (DOUT), MULED2.2 (DIN)
unnamed: MULED2.4 (DOUT), MULED3.2 (DIN)
unnamed: SLED1.4 (DOUT), SLED2.2 (DIN)
unnamed: SLED2.4 (DOUT), SLED3.2 (DIN)
unnamed: SLED3.4 (DOUT), SLED4.2 (DIN)
unnamed: SLED4.4 (DOUT), SLED5.2 (DIN)
unnamed: SLED5.4 (DOUT), SLED6.2 (DIN)
unnamed: SLED6.4 (DOUT), SLED7.2 (DIN)
unnamed: SLED7.4 (DOUT), SLED8.2 (DIN)
unnamed: SLED8.4 (DOUT), SLED9.2 (DIN)
unnamed: SLED9.4 (DOUT), SLED10.2 (DIN)
unnamed: SLED10.4 (DOUT), SLED11.2 (DIN)
unnamed: SLED11.4 (DOUT), SLED12.2 (DIN)
unnamed: SLED12.4 (DOUT), SLED13.2 (DIN)
unnamed: SLED13.4 (DOUT), SLED14.2 (DIN)
unnamed: SLED14.4 (DOUT), SLED15.2 (DIN)
unnamed: SLED15.4 (DOUT), SLED16.2 (DIN)
unnamed: SLED16.4 (DOUT), SLED17.2 (DIN)
unnamed: SLED17.4 (DOUT), SLED18.2 (DIN)
unnamed: SLED18.4 (DOUT), SLED19.2 (DIN)
unnamed: SLED19.4 (DOUT), SLED20.2 (DIN)
unnamed: SLED20.4 (DOUT), SLED21.2 (DIN)
unnamed: SLED21.4 (DOUT), SLED22.2 (DIN)
unnamed: SULED1.4 (DOUT), SULED2.2 (DIN)
unnamed: TLED1.4 (DOUT), TLED2.2 (DIN)
unnamed: TLED2.4 (DOUT), TLED3.2 (DIN)
unnamed: TLED3.4 (DOUT), TLED4.2 (DIN)
unnamed: TLED4.4 (DOUT), TLED5.2 (DIN)
unnamed: TLED5.4 (DOUT), TLED6.2 (DIN)
VSYS: MLED1.3 (VDD), MLED2.3 (VDD), MLED3.3 (VDD), MLED4.3 (VDD), MLED5.3 (VDD), MLED6.3 (VDD), MLED7.3 (VDD), MLED8.3 (VDD), MLED9.3 (VDD), MLED10.3 (VDD), MLED11.3 (VDD), MLED12.3 (VDD), MLED13.3 (VDD), MLED14.3 (VDD), MLED15.3 (VDD), MLED16.3 (VDD), MLED17.3 (VDD), MLED18.3 (VDD), MLED19.3 (VDD), MLED20.3 (VDD), MLED21.3 (VDD), MLED22.3 (VDD), MLED23.3 (VDD), MLED24.3 (VDD), MLED25.3 (VDD), MLED26.3 (VDD), MLED27.3 (VDD), MLED28.3 (VDD), MLED29.3 (VDD), MULED1.3 (VDD), MULED2.3 (VDD), MULED3.3 (VDD), SLED1.3 (VDD), SLED2.3 (VDD), SLED3.3 (VDD), SLED4.3 (VDD), SLED5.3 (VDD), SLED6.3 (VDD), SLED7.3 (VDD), SLED8.3 (VDD), SLED9.3 (VDD), SLED10.3 (VDD), SLED11.3 (VDD), SLED12.3 (VDD), SLED13.3 (VDD), SLED14.3 (VDD), SLED15.3 (VDD), SLED16.3 (VDD), SLED17.3 (VDD), SLED18.3 (VDD), SLED19.3 (VDD), SLED20.3 (VDD), SLED21.3 (VDD), SLED22.3 (VDD), SULED1.3 (VDD), SULED2.3 (VDD), TLED1.3 (VDD), TLED2.3 (VDD), TLED3.3 (VDD), TLED4.3 (VDD), TLED5.3 (VDD), TLED6.3 (VDD); also elsewhere on the board
nLED_U: SLED22.4 (DOUT), SULED1.2 (DIN)

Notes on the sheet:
All LEDs

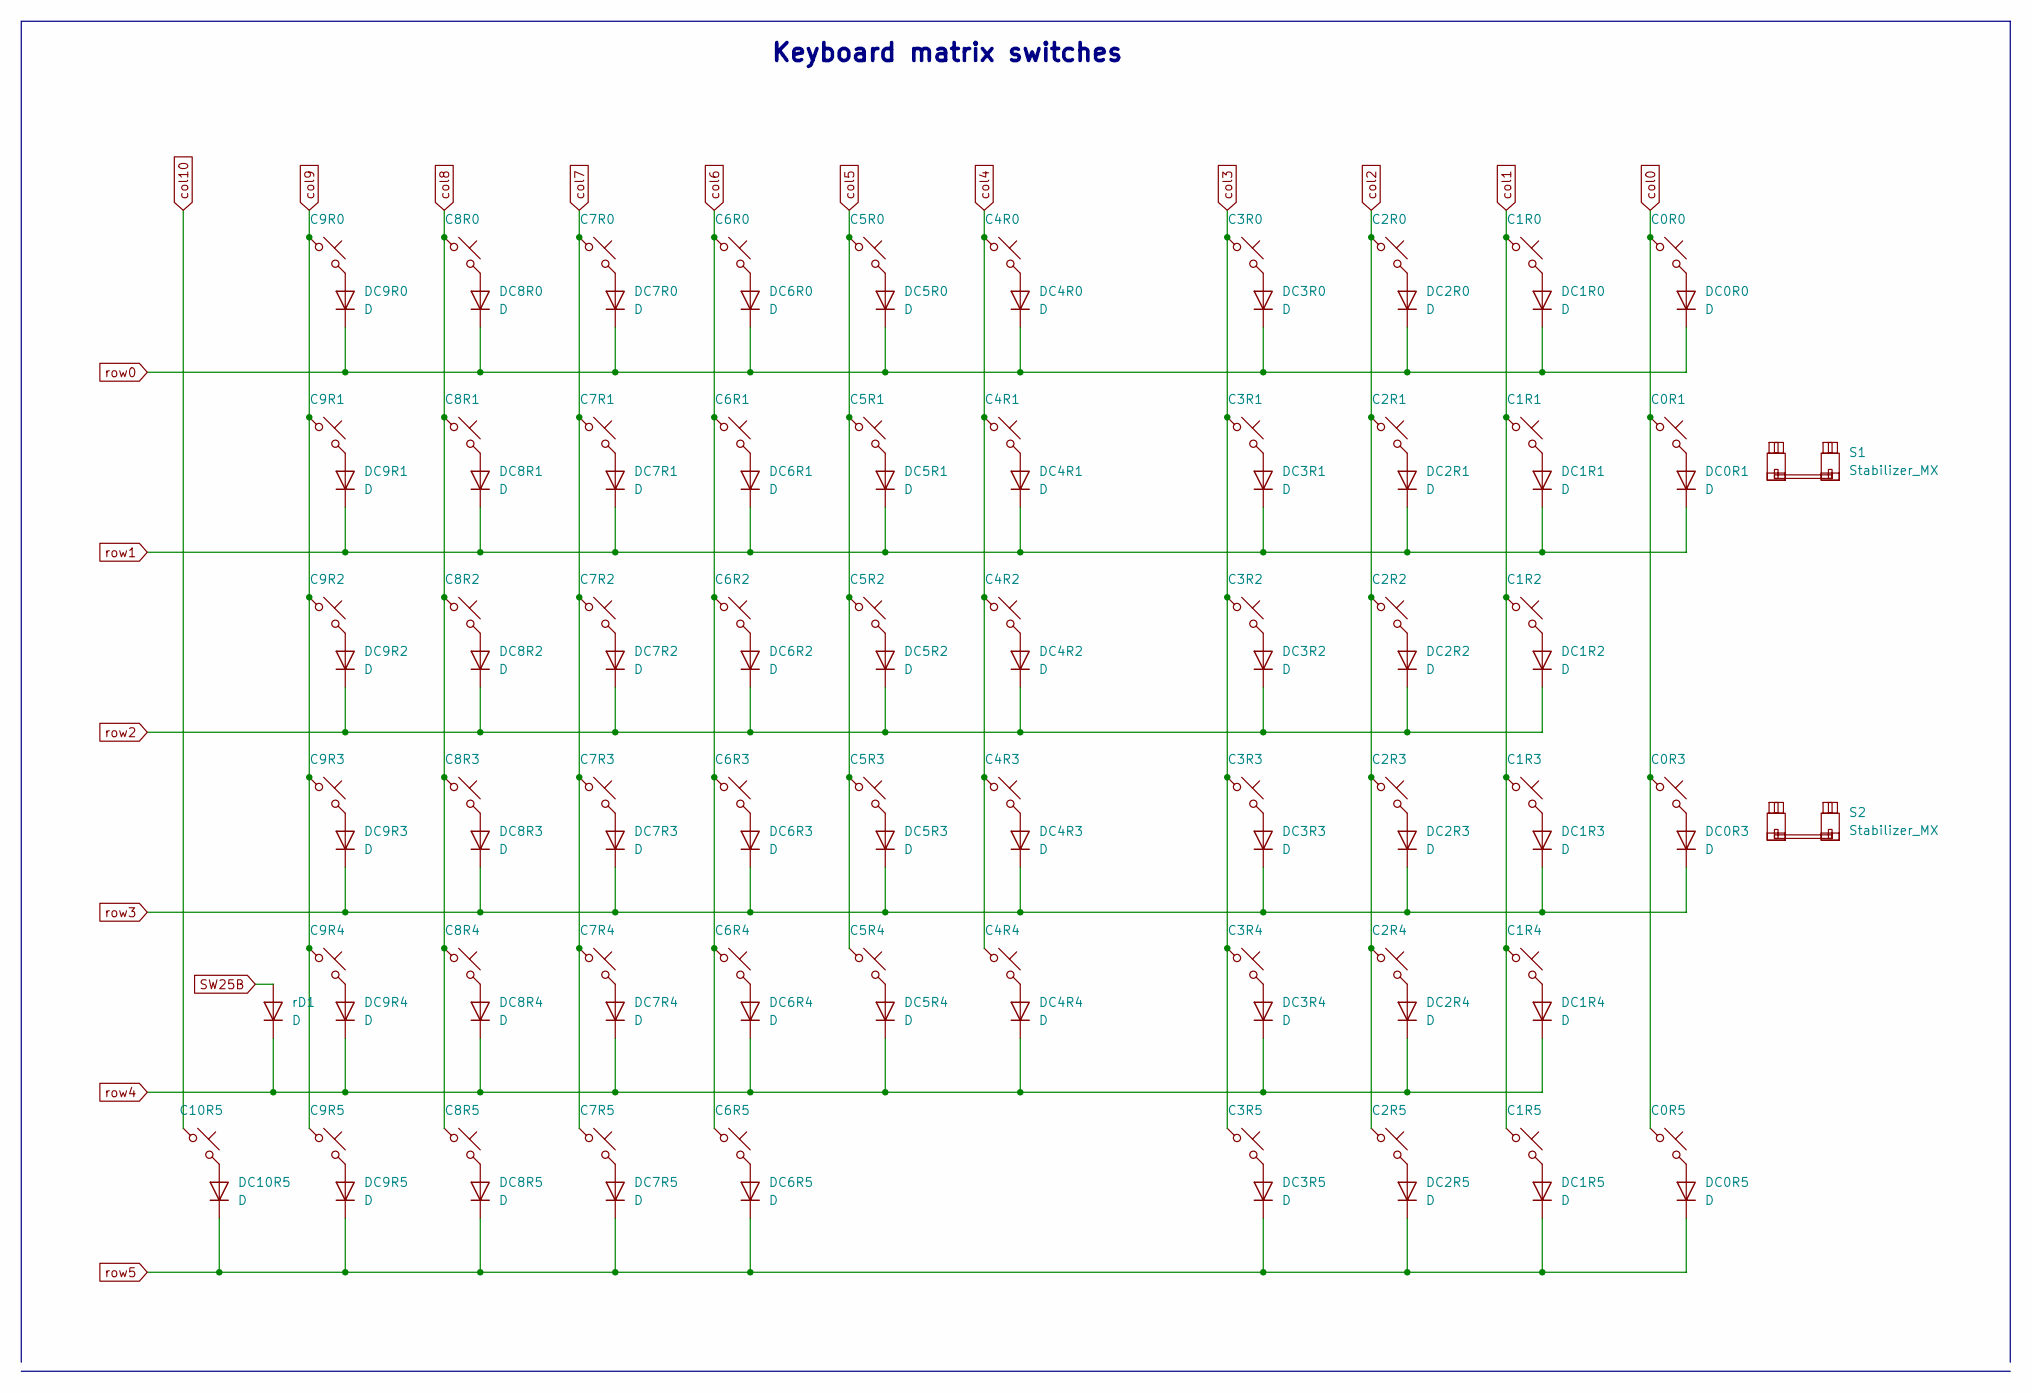
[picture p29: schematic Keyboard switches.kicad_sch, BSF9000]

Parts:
C0R0, C0R1, C0R3, C0R5, C1R0, C1R1, C1R2, C1R3, C1R4, C1R5, C2R0, C2R1, C2R2, C2R3, C2R4, C2R5, C3R0, C3R1, C3R2, C3R3, C3R4, C3R5, C4R0, C4R1, C4R2, C4R3, C4R4, C5R0, C5R1, C5R2, C5R3, C5R4, C6R0, C6R1, C6R2, C6R3, C6R4, C6R5, C7R0, C7R1, C7R2, C7R3, C7R4, C7R5, C8R0, C8R1, C8R2, C8R3, C8R4, C8R5, C9R0, C9R1, C9R2, C9R3, C9R4, C9R5, C10R5: MX_SW_HS; SW_Cherry_MX_Hotswap_DS; MFG PN CPG151101S11-16; JLCPCB_PN C41430893
DC0R0, DC0R1, DC0R3, DC0R5, DC1R0, DC1R1, DC1R2, DC1R3, DC1R4, DC1R5, DC2R0, DC2R1, DC2R2, DC2R3, DC2R4, DC2R5, DC3R0, DC3R1, DC3R2, DC3R3, DC3R4, DC3R5, DC4R0, DC4R1, DC4R2, DC4R3, DC4R4, DC5R0, DC5R1, DC5R2, DC5R3, DC5R4, DC6R0, DC6R1, DC6R2, DC6R3, DC6R4, DC6R5, DC7R0, DC7R1, DC7R2, DC7R3, DC7R4, DC7R5, DC8R0, DC8R1, DC8R2, DC8R3, DC8R4, DC8R5, DC9R0, DC9R1, DC9R2, DC9R3, DC9R4, DC9R5, DC10R5: D; D_Hybrid_SOD-123_DO-35_DS; Voltage Rating 75v; MFG PN 1N4148W; JLCPCB_PN C81598
S1, S2: Stabilizer_MX; Stabilizer_MX_2u; MFG PN DNP; JLCPCB_PN DNP
rD1: D; D_Hybrid_SOD-123_DO-35_DS; Voltage Rating 75v; MFG PN 1N4148W; JLCPCB_PN C81598

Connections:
unnamed: C0R0.2, DC0R0.2 (A)
unnamed: C0R1.2, DC0R1.2 (A)
unnamed: C0R3.2, DC0R3.2 (A)
unnamed: C0R5.2, DC0R5.2 (A)
unnamed: C1R0.2, DC1R0.2 (A)
unnamed: C1R1.2, DC1R1.2 (A)
unnamed: C1R2.2, DC1R2.2 (A)
unnamed: C1R3.2, DC1R3.2 (A)
unnamed: C1R4.2, DC1R4.2 (A)
unnamed: C1R5.2, DC1R5.2 (A)
unnamed: C2R0.2, DC2R0.2 (A)
unnamed: C2R1.2, DC2R1.2 (A)
unnamed: C2R2.2, DC2R2.2 (A)
unnamed: C2R3.2, DC2R3.2 (A)
unnamed: C2R4.2, DC2R4.2 (A)
unnamed: C2R5.2, DC2R5.2 (A)
unnamed: C3R0.2, DC3R0.2 (A)
unnamed: C3R1.2, DC3R1.2 (A)
unnamed: C3R2.2, DC3R2.2 (A)
unnamed: C3R3.2, DC3R3.2 (A)
unnamed: C3R4.2, DC3R4.2 (A)
unnamed: C3R5.2, DC3R5.2 (A)
unnamed: C4R0.2, DC4R0.2 (A)
unnamed: C4R1.2, DC4R1.2 (A)
unnamed: C4R2.2, DC4R2.2 (A)
unnamed: C4R3.2, DC4R3.2 (A)
unnamed: C4R4.2, DC4R4.2 (A)
unnamed: C5R0.2, DC5R0.2 (A)
unnamed: C5R1.2, DC5R1.2 (A)
unnamed: C5R2.2, DC5R2.2 (A)
unnamed: C5R3.2, DC5R3.2 (A)
unnamed: C5R4.2, DC5R4.2 (A)
unnamed: C6R0.2, DC6R0.2 (A)
unnamed: C6R1.2, DC6R1.2 (A)
unnamed: C6R2.2, DC6R2.2 (A)
unnamed: C6R3.2, DC6R3.2 (A)
unnamed: C6R4.2, DC6R4.2 (A)
unnamed: C6R5.2, DC6R5.2 (A)
unnamed: C7R0.2, DC7R0.2 (A)
unnamed: C7R1.2, DC7R1.2 (A)
unnamed: C7R2.2, DC7R2.2 (A)
unnamed: C7R3.2, DC7R3.2 (A)
unnamed: C7R4.2, DC7R4.2 (A)
unnamed: C7R5.2, DC7R5.2 (A)
unnamed: C8R0.2, DC8R0.2 (A)
unnamed: C8R1.2, DC8R1.2 (A)
unnamed: C8R2.2, DC8R2.2 (A)
unnamed: C8R3.2, DC8R3.2 (A)
unnamed: C8R4.2, DC8R4.2 (A)
unnamed: C8R5.2, DC8R5.2 (A)
unnamed: C9R0.2, DC9R0.2 (A)
unnamed: C9R1.2, DC9R1.2 (A)
unnamed: C9R2.2, DC9R2.2 (A)
unnamed: C9R3.2, DC9R3.2 (A)
unnamed: C9R4.2, DC9R4.2 (A)
unnamed: C9R5.2, DC9R5.2 (A)
unnamed: C10R5.2, DC10R5.2 (A)
SW25B: rD1.2 (A); also elsewhere on the board
col0: C0R0.1, C0R1.1, C0R3.1, C0R5.1; also elsewhere on the board
col1: C1R0.1, C1R1.1, C1R2.1, C1R3.1, C1R4.1, C1R5.1; also elsewhere on the board
col2: C2R0.1, C2R1.1, C2R2.1, C2R3.1, C2R4.1, C2R5.1; also elsewhere on the board
col3: C3R0.1, C3R1.1, C3R2.1, C3R3.1, C3R4.1, C3R5.1; also elsewhere on the board
col4: C4R0.1, C4R1.1, C4R2.1, C4R3.1, C4R4.1; also elsewhere on the board
col5: C5R0.1, C5R1.1, C5R2.1, C5R3.1, C5R4.1; also elsewhere on the board
col6: C6R0.1, C6R1.1, C6R2.1, C6R3.1, C6R4.1, C6R5.1; also elsewhere on the board
col7: C7R0.1, C7R1.1, C7R2.1, C7R3.1, C7R4.1, C7R5.1; also elsewhere on the board
col8: C8R0.1, C8R1.1, C8R2.1, C8R3.1, C8R4.1, C8R5.1; also elsewhere on the board
col9: C9R0.1, C9R1.1, C9R2.1, C9R3.1, C9R4.1, C9R5.1; also elsewhere on the board
col10: C10R5.1; also elsewhere on the board
row0: DC0R0.1 (K), DC1R0.1 (K), DC2R0.1 (K), DC3R0.1 (K), DC4R0.1 (K), DC5R0.1 (K), DC6R0.1 (K), DC7R0.1 (K), DC8R0.1 (K), DC9R0.1 (K); also elsewhere on the board
row1: DC0R1.1 (K), DC1R1.1 (K), DC2R1.1 (K), DC3R1.1 (K), DC4R1.1 (K), DC5R1.1 (K), DC6R1.1 (K), DC7R1.1 (K), DC8R1.1 (K), DC9R1.1 (K); also elsewhere on the board
row2: DC1R2.1 (K), DC2R2.1 (K), DC3R2.1 (K), DC4R2.1 (K), DC5R2.1 (K), DC6R2.1 (K), DC7R2.1 (K), DC8R2.1 (K), DC9R2.1 (K); also elsewhere on the board
row3: DC0R3.1 (K), DC1R3.1 (K), DC2R3.1 (K), DC3R3.1 (K), DC4R3.1 (K), DC5R3.1 (K), DC6R3.1 (K), DC7R3.1 (K), DC8R3.1 (K), DC9R3.1 (K); also elsewhere on the board
row4: DC1R4.1 (K), DC2R4.1 (K), DC3R4.1 (K), DC4R4.1 (K), DC5R4.1 (K), DC6R4.1 (K), DC7R4.1 (K), DC8R4.1 (K), DC9R4.1 (K), rD1.1 (K); also elsewhere on the board
row5: DC0R5.1 (K), DC1R5.1 (K), DC2R5.1 (K), DC3R5.1 (K), DC6R5.1 (K), DC7R5.1 (K), DC8R5.1 (K), DC9R5.1 (K), DC10R5.1 (K); also elsewhere on the board

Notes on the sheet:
Keyboard matrix switches

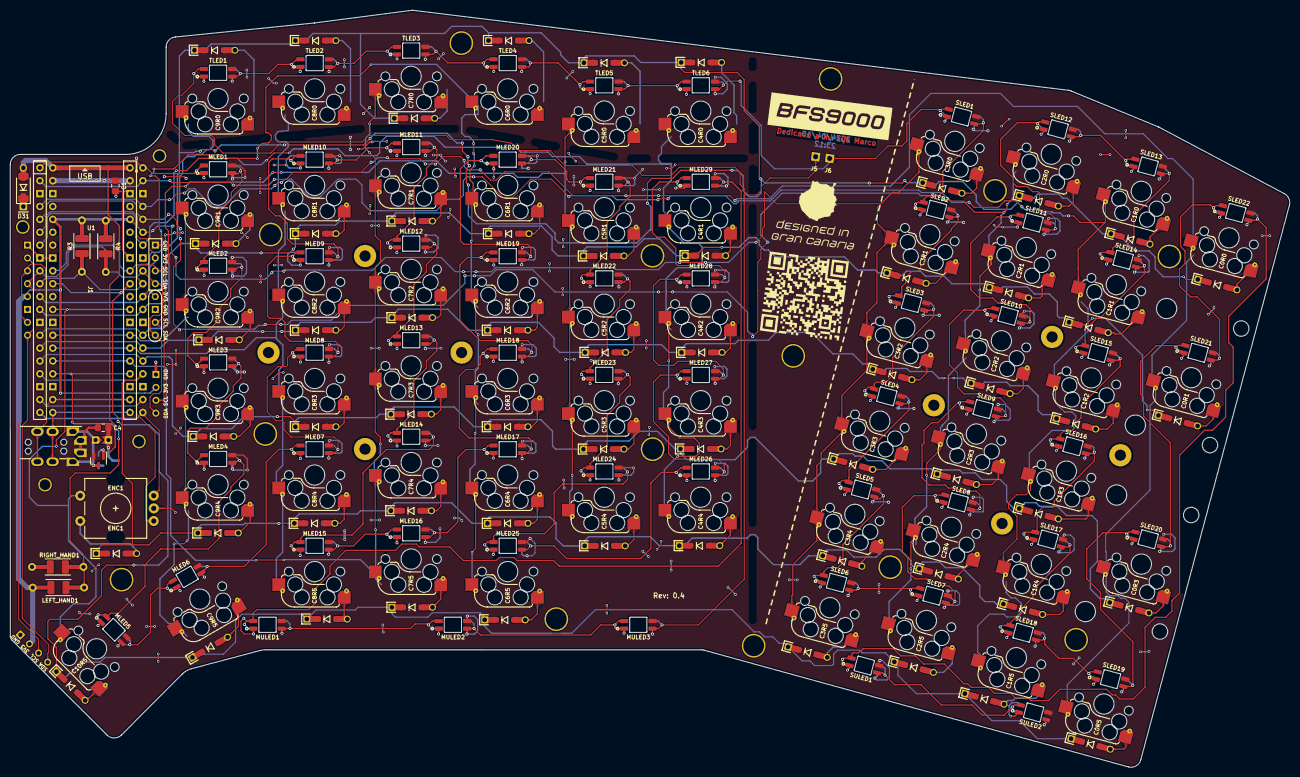
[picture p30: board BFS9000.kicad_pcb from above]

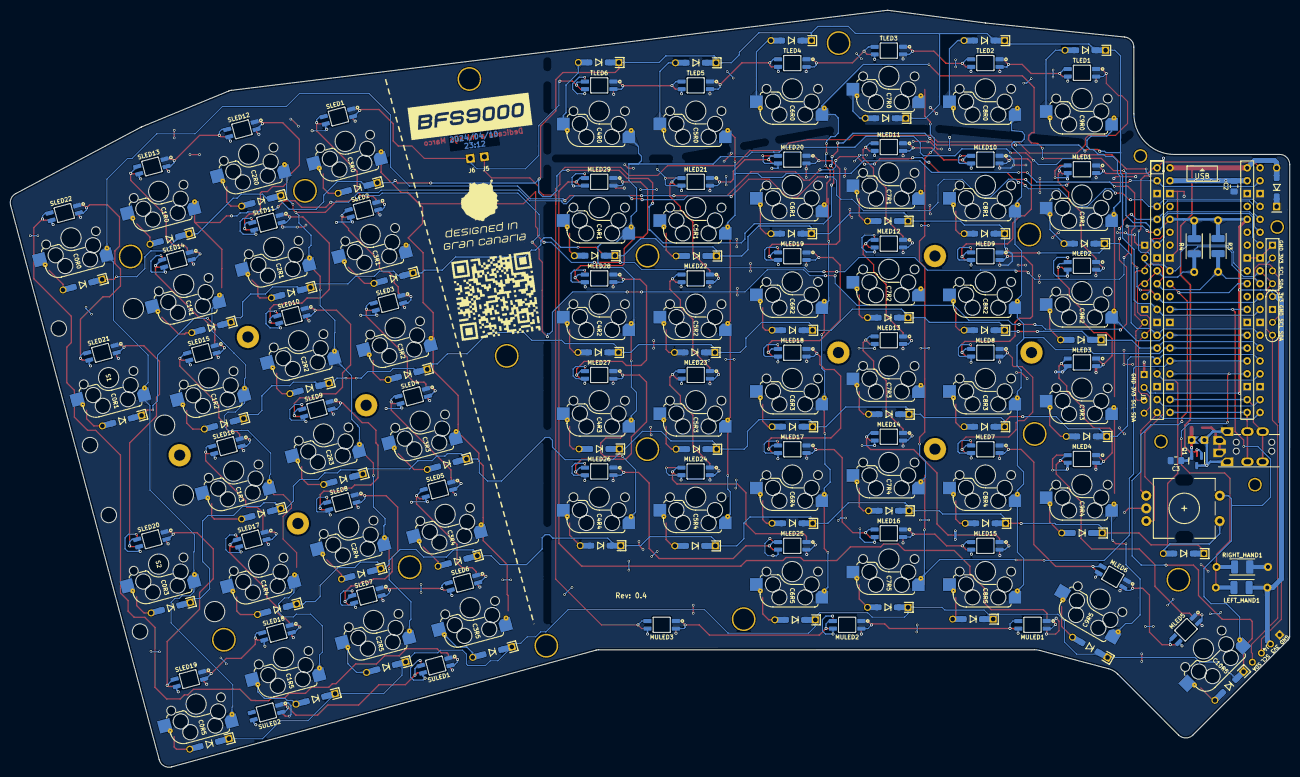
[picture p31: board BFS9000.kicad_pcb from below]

Board: 2 copper layers, 252.5 x 149.4 mm, 237 parts (188 on the bottom side), 149 nets.

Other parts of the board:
BFS9000_Back, BFS9000_Front: LOGO; Logo_BFS9000_Gran_Canaria
D31_B: D_SOD-128
Wiki_Back: QR; QR_Wiki
Wiki_Front: QR; QR_Wiki

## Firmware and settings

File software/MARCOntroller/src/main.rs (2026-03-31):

// ============================================================================
// MARCOntroller — VialRGB keyboard lighting controller over USB HID
// ============================================================================
//
// MIT License
//
// Copyright (c) 2026 Jesús Guillén (jguillen-lab)
//
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
// ============================================================================

#[macro_use]
extern crate rust_i18n;
i18n!("locales", fallback = "en");

use clap::Parser;
use sys_locale::get_locale;

mod agent;
mod cli;
mod config;
mod keyboard;
mod logging;
mod service;
mod ui;

#[tokio::main]
async fn main() -> anyhow::Result<()> {
    // ── 1. Parse CLI args ────────────────────────────────────────────────────
    let cli = cli::Cli::parse();

    // ── 2. Logging ──────────────────────────────────────────────────────────
    //
    // Console/UI mode keeps stdout logging. Service mode switches to a file
    // logger so diagnostics remain available without an attached terminal.
    let is_service_mode = matches!(cli.cmd, cli::Command::Service);
    logging::init(is_service_mode, cli.config.as_deref());

    // ── 3. Detect and set locale ─────────────────────────────────────────────
    let locale = detect_lang(cli.lang.as_deref());
    rust_i18n::set_locale(&locale);

    // ── 4. Dispatch ──────────────────────────────────────────────────────────
    cli::run(cli, locale).await
}

/// Resolve the active locale code from (in priority order):
///   1. `--lang` CLI flag
///   2. `MARCOCONTROLLER_LANG` environment variable
///   3. `LC_ALL` / `LC_MESSAGES` / `LANG` / `LANGUAGE`
///   4. System locale via platform API
///   5. `"en"` built-in default
///
/// Returns a supported locale code string (e.g. `"en"`, `"es"`).
fn detect_lang(cli_override: Option<&str>) -> String {
    if let Some(code) = cli_override {
        return normalise_locale(code);
    }

    if let Ok(v) = std::env::var("MARCOCONTROLLER_LANG")
        && !v.trim().is_empty()
    {
        return normalise_locale(&v);
    }

    for key in ["LC_ALL", "LC_MESSAGES", "LANG", "LANGUAGE"] {
        if let Ok(v) = std::env::var(key) {
            let trimmed = v.trim();
            if !trimmed.is_empty() {
                return normalise_locale(trimmed);
            }
        }
    }

    if let Some(v) = get_locale() {
        return normalise_locale(&v);
    }

    "en".to_owned()
}

/// Map a locale string to a supported code, defaulting to `"en"`.
///
/// Accepts common forms such as:
/// - "es"
/// - "es-ES"
/// - "es_ES.UTF-8"
/// - "en-US"
/// - "English_United States"
fn normalise_locale(code: &str) -> String {
    let lower = code.trim().to_lowercase();

    let primary = lower.split(['-', '_', '.', '@']).next().unwrap_or("");

    match primary {
        "es" => "es".to_owned(),
        "en" => "en".to_owned(),
        _ => {
            if lower.starts_with("spanish") {
                "es".to_owned()
            } else {
                "en".to_owned()
            }
        }
    }
}

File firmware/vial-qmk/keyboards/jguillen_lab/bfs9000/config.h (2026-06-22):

/* SPDX-License-Identifier: GPL-2.0-or-later
 *
 * BFS9000 — Keyboard-level firmware configuration
 * Copyright (C) 2026 jguillen-lab
 *
 * This file is part of the BFS9000 / Marquichuelo keyboard firmware.
 * It is distributed under the terms of the GNU General Public License
 * version 2 or later.
 */

#pragma once

/* ─────────────────────────────────────────────────────────────────────────────
 * SPLIT SERIAL TRANSPORT
 * ─────────────────────────────────────────────────────────────────────────────
 *
 * The BFS9000 is a split keyboard. These defines configure the serial link
 * used by QMK to exchange matrix state, LED state and user transactions between
 * the two halves.
 *
 * SERIAL_USART_FULL_DUPLEX
 *   Enables independent TX and RX wires instead of half-duplex communication.
 *
 * SERIAL_USART_TX_PIN / SERIAL_USART_RX_PIN
 *   RP2040 GPIO pins used by the serial transport.
 *
 * SERIAL_USART_PIN_SWAP
 *   Swaps the UART pin mapping when the selected peripheral/pin pair requires
 *   it. Keep this aligned with the PCB wiring.
 */
#define SERIAL_USART_FULL_DUPLEX
#define SERIAL_USART_TX_PIN GP16
#define SERIAL_USART_RX_PIN GP17
#define SERIAL_USART_PIN_SWAP

/* ─────────────────────────────────────────────────────────────────────────────
 * SPLIT SIDE DETECTION
 * ─────────────────────────────────────────────────────────────────────────────
 *
 * SPLIT_HAND_PIN tells QMK which GPIO is used to decide whether this half is
 * the left or right side. The electrical pull direction is defined by the PCB
 * wiring and the corresponding QMK split-hand configuration.
 */
#define SPLIT_HAND_PIN GP18

/* ─────────────────────────────────────────────────────────────────────────────
 * OLED I²C BUS
 * ─────────────────────────────────────────────────────────────────────────────
 *
 * The OLED display is connected to I²C1 on the RP2040.
 * These pins must match the PCB routing.
 */
#define I2C_DRIVER I2CD1
#define I2C1_SDA_PIN GP6
#define I2C1_SCL_PIN GP7

/* ─────────────────────────────────────────────────────────────────────────────
 * OLED DISPLAY DEFAULTS
 * ─────────────────────────────────────────────────────────────────────────────
 *
 * Only compiled when OLED_ENABLE=yes is active in the keymap rules.
 *
 * OLED_DISPLAY_128X64
 *   Selects a 128×64 panel layout.
 *
 * OLED_TIMEOUT 0
 *   Keeps the display permanently on.
 *
 * OLED_UPDATE_INTERVAL 50
 *   Refreshes the OLED roughly every 50 ms. This is responsive enough for
 *   status updates without needlessly refreshing every matrix scan.
 */
#ifdef OLED_ENABLE
#    define OLED_DISPLAY_128X64
#    define OLED_TIMEOUT 0
#    define OLED_UPDATE_INTERVAL 50
#endif

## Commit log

2026-03-07 feat(locales): add MQTT agent status messages
    fix(cli): pass locale to ui run method
    refactor(main): enhance lang detection logic
    refactor(ui): update UI model for agent events
    [cli.rs, main.rs]
2026-03-28 feat(vial): add pointing device configuration for trackpad docs(vial): update config documentation for pointing device settings refactor(rules): enable and configure pointing device subsystem
2026-03-31 feat(workflows): add pcb-render-manual-yml chore(gitignore): exclude history-directory
2026-03-31 chore(pcb-render-manual): update rendering workflow parameters and remove 3D render steps
2026-03-31 feat(workflows): add PCB render manual workflow
2026-03-31 chore(pcb-render-manual): update KiCad installation to official 9.0 release
2026-04-06 feat(vial-qmk): add bfs9000 keyboard support
    Add initial firmware support for the BFS9000, a custom wireless-split
    ergonomic keyboard based on the RP2040 microcontroller.
    Features configured:
    - Split keyboard over TRRS (full-duplex UART via RP2040 PIO vendor driver)
    - Hardware handedness detection via SPLIT_HAND_PIN (GP18)
    - Per-key RGB matrix (WS2812B, vendor/PIO driver, 124 LEDs per side)
    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
2026-04-26 feat(pcb): add BFS9000 bottom plate design
    [BFS9000 bottom plate.kicad_pcb]
2026-04-26 feat(hardware): add BFS9000 switch plate design files
    [BFS9000 switch plate.kicad_pcb]
2026-04-27 fix(hw-BFS9000bp): update plot settings and version chore(hw-BFS9000bp): add tuning profile and uuid for top sheet
    [BFS9000 bottom plate.kicad_pcb]
2026-04-27 fix(BFS9000 switch plate): update date and position of text component
    [BFS9000 switch plate.kicad_pcb]
2026-04-27 docs(bfs9000-switch-plate): update comment description
    [BFS9000 switch plate.kicad_pcb]
2026-04-27 fix(BFS9000 switch plate): update plot output directory and layer selection in PCB files
    [BFS9000 bottom plate.kicad_pcb, BFS9000 switch plate.kicad_pcb]
2026-05-01 docs(bfs9000): add hardware documentation files feat(bfs9000): create GPIO pin mapping table
    [PIN-GPIO-COL-ROW.ods]
2026-05-01 fix(board_layout): update mounting holes and cutouts positions
    [BFS9000.kicad_sch, Breakaway tabs.kicad_sch]
2026-05-01 update(project): integrate BFS9000 schematic and layout
2026-05-01 chore(hardware): add BFS9000 edge cuts and holes
    [BFS9000.kicad_pcb]
2026-05-02 feat(hardware): add footprints for all switches
    [BFS9000.kicad_pcb]
2026-05-03 feat(hardware): add RP2040 footprint and peripheral circuitry
    Add the RP2040 footprint, decoupling capacitors, OLED connectors, I2C pull-up resistors, and left/right keyboard side detection circuitry.
    [BFS9000.kicad_pcb, BFS9000.kicad_sch, Breakaway tabs.kicad_sch]
2026-05-06 feat(hardware): integrate RGB and switch matrix layout
    Add dedicated schematic sheets for addressable RGB LEDs and keyboard switches.
    Place SK6803 MINI-E LEDs, MX switch footprints, stabilizers, rotary encoder, jack connector, and related power/control components in the BFS9000 PCB layout.
    Update the main schematic, project settings, and breakaway tabs sheet to match the expanded hardware design.
    [Addressable RGB LEDs.kicad_sch, BFS9000.kicad_sch, Breakaway tabs.kicad_sch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]
2026-05-21 feat(hardware): add local KiCad libraries
2026-05-21 feat(hardware): update BFS9000 schematic and PCB layout
    [Addressable RGB LEDs.kicad_sch, BFS9000.kicad_pcb, BFS9000.kicad_sch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]
2026-05-21 docs(bfs9000): update version to 0.4 docs(bfs9000): reflect current development status
2026-05-21 feat(hardware): add PCB teardrops
    [BFS9000.kicad_pcb]
2026-06-22 feat(vial-qmk): add RGB matrix and split LED support
    Enable RGB Matrix effects, define physical LED layout, and implement
    split
    LED state synchronization.
    Enable TPS65/Azoteq IQS5xx trackpad driver for right half.
2026-06-22 feat(vial-qmk): update keyboard layout and configuration
    - Adjusted matrix pin assignments
    - Removed encoder_map feature
    - Reduced encoder resolution
    - Simplified layout structure
2026-06-22 feat(vial-qmk): enable RGB matrix, OLED, combo, tap dance, and pointing device
    Add support for RGB matrix, OLED display, combo keys, tap dance actions,
    and a pointing device driver in VIAL configuration.
2026-06-22 feat(vial-qmk): add SPDX license header and expand build rules
    - Add SPDX-License-Identifier to top of file.
    - Document MCU, bootloader, serial driver, and OLED settings.
    - Expand comments for better understanding.
2026-06-22 fix(pcb): refill copper zones
    [BFS9000.kicad_pcb]
2026-06-24 fix(vial-qmk): update device version in keyboard.json
    Update the device version to 0.4 in the BFS9000 keyboard configuration.
2026-06-24 feat(hardware): add new enclosure designs and CNC files
    Add various 3D models and DXF files for different sections of the
    BFS9000 enclosure including bottom, screen, switch parts, and TPS65
    specific components. These updates include new configurations such as
    full bottom with window and sectionable variants.
    [A_BFS9000_sectionable_bottom.3mf, A_BFS9000_sectionable_bottom_tps65.3mf, A_BFS9000_sectionable_switch.3mf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]
2026-06-24 chore(hardware): add new binary files for rev0.4 plates and PCB
    add gerbers drill file for PCB
    add bottom plate zip file
    add switch plate zip file
2026-06-24 docs(hardware): add Spanish and English README files for BFS9000 hardware documentation
    chore(hardware): update production and enclosures directory structure
    documentation in README files
2026-06-24 docs(media): add new full images for BFS9000
    Include multiple angles for detailed visualization with TPS65 magnets
2026-06-28 feat(vial-qmk): add USR boot pin and task
    Define USR_BOOT_PIN for bootloader entry.
    Implement usr_boot_task to handle button press.
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2026-07-12 feat(hardware): add new 3mf files
    [D31_spacer.3mf, diode_leg_bender.3mf, screen_protector_riser_bottom.3mf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]
